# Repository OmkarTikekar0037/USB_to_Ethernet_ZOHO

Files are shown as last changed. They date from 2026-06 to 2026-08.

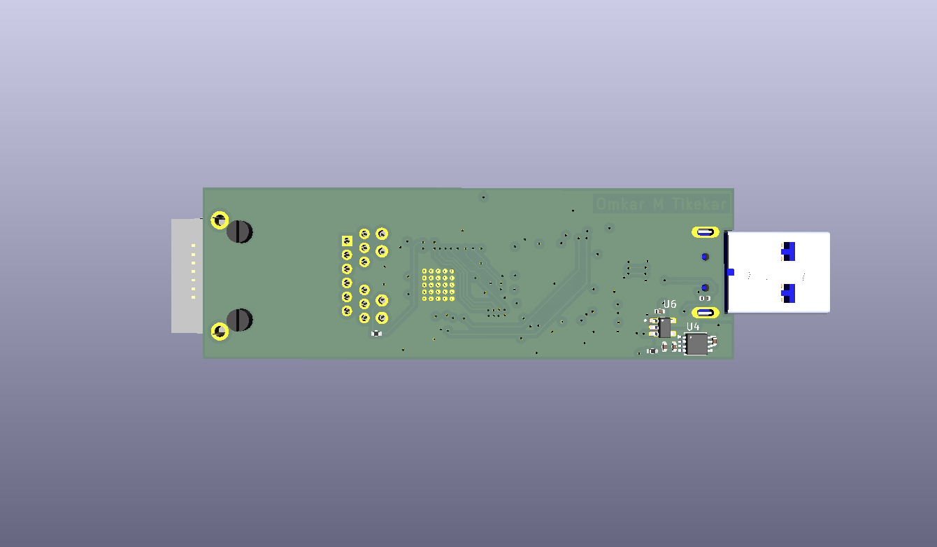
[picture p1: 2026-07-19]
images/USB_3.1_to_Ethernet_3d_B.png

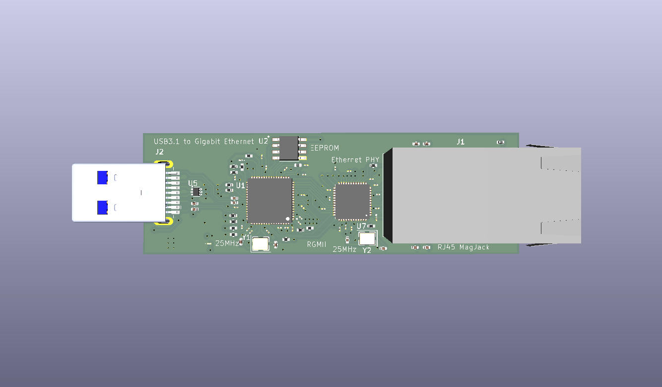
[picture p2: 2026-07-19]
images/USB_3.1_to_Ethernet_3d_F.png

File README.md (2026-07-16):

# USB 3.1 Gen 1 to Gigabit Ethernet Adapter

A custom 4-layer PCB implementing a USB 3.1 Gen 1 to Gigabit Ethernet adapter based on the **Microchip LAN7801** USB-to-Ethernet controller and the **KSZ9031RNX** Gigabit Ethernet PHY.

The project focuses on producing a manufacturable hardware design by following industry-standard practices for high-speed PCB layout, power distribution, signal integrity, and Ethernet design.

---

## Project Objectives

- Design a production-quality USB 3.1 Gen 1 to Gigabit Ethernet adapter.
- Implement a complete RGMII-based Ethernet subsystem.
- Develop a reliable multi-rail power architecture.
- Follow high-speed PCB design guidelines for USB and Gigabit Ethernet.
- Produce fabrication-ready design files with zero ERC/DRC violations.

---

## Hardware Overview

| Component | Description |
|---|---|
| LAN7801 | USB 3.1 Gen 1 to Gigabit Ethernet Controller |
| KSZ9031RNX | Gigabit Ethernet PHY |
| 93LC56 | External configuration EEPROM |
| USB Type-C | USB Interface |
| RJ45 MagJack | Ethernet Connector with Integrated Magnetics |
| TLV76733 | 3.3V LDO |
| TPS7A0212 | 1.2V LDO |

---

## System Architecture

```
USB Type-C
      │
      ▼
+--------------+
|   LAN7801    |
+--------------+
      │
     RGMII
      │
      ▼
+--------------+
| KSZ9031RNX   |
+--------------+
      │
 Ethernet MDI
      │
      ▼
 RJ45 MagJack
```

---

## Repository Structure

```text
.
├── Hardware/
│   ├── Schematic/
│   ├── PCB/
│   ├── Libraries/
│   └── Manufacturing/
│
├── Docs/
│   ├── Project_History.md
│   ├── System_Architecture.md
│   ├── Power_Architecture.md
│   ├── Ethernet_Subsystem.md
│   ├── USB_Subsystem.md
│   ├── PCB_Design.md
│   └── Debugging.md
│
├── Datasheets/
│
├── Images/
│
└── README.md
```

---

## Current Project Status

| Stage | Status |
|---|---|
| Component Selection | Completed |
| Schematic Design | Completed |
| PCB Placement | Completed |
| PCB Routing | Completed |
| ERC | Passed |
| DRC | Passed |
| Manufacturing Outputs | In Progress |
| Hardware Validation | Pending |

---

## Design Highlights

- 4-layer PCB stack-up
- Controlled impedance routing
- USB differential pair routing
- Gigabit Ethernet differential routing
- Dedicated power planes
- Multi-stage power regulation
- External EEPROM configuration
- RGMII interface between MAC and PHY
- ESD and signal protection provisions

---

## Documentation

Detailed design discussions and engineering decisions are maintained separately under the **Docs** directory.

These documents describe:

- Architecture
- Design decisions
- Power subsystem
- PCB layout methodology
- Signal integrity considerations
- Manufacturing preparation
- Debugging history

The README intentionally provides only a high-level overview.

---

## Future Work

- PCB fabrication
- Assembly
- Hardware bring-up
- USB enumeration verification
- Ethernet link validation
- Throughput testing
- Compliance verification

---

## License

Project license to be added.

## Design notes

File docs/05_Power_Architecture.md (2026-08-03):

# Power Architecture

## 1. Introduction

The power architecture provides regulated supply rails for every subsystem of the adapter, beginning with the 5 V supplied through the USB Type-A connector.

The design emphasizes:

- Stable voltage regulation
- Low-noise power distribution
- Proper subsystem isolation
- Reliable startup
- Adequate local decoupling
- Manufacturable PCB layout

The power network was designed to satisfy the requirements of both the LAN7801 controller and the KSZ9031RNX Gigabit Ethernet PHY while maintaining good signal integrity throughout the board.

---

# 2. Power Overview

The entire adapter is powered directly from the USB VBUS supply.

```

                USB VBUS (5 V)
                       │
                       ▼
             +------------------+
             |    3.3 V LDO     |
             +------------------+
                       │
        ┌──────────────┼──────────────┐
        │              │              │
        ▼              ▼              ▼
    LAN7801       KSZ9031RNX      EEPROM
      I/O             I/O
                       │
                       ▼
              +------------------+
              |    1.2 V LDO     |
              +------------------+
                       │
         ┌─────────────┴─────────────┐
         ▼                           ▼
   LAN7801 Core             KSZ9031RNX Core

```

The design uses a cascaded regulation approach where the 3.3 V rail supplies the lower-voltage regulator required for the core logic.

---

# 3. Supply Rails

## 3.1 USB VBUS (5 V)

The USB connector provides the primary power source for the board.

This rail serves as the input to the onboard voltage regulation circuitry and is not distributed directly to digital logic.

Primary responsibilities:

- System power input
- Regulator input supply

---

## 3.2 3.3 V Rail

The 3.3 V rail supplies the I/O circuitry and supporting peripherals.

Typical loads include:

- LAN7801 I/O
- KSZ9031RNX I/O
- EEPROM
- Supporting logic

This rail also serves as the input source for the 1.2 V regulator.

---

## 3.3 1.2 V Rail

The 1.2 V rail powers the internal core logic of the major integrated circuits.

Typical loads include:

- LAN7801 Core
- KSZ9031RNX Core
- Internal digital logic

Because these circuits switch at high frequency, particular attention was given to local decoupling and power plane integrity.

---

# 4. Power Tree

```

                    USB VBUS
                        │
                        ▼
                 3.3 V Regulator
                        │
      ┌─────────────────┼─────────────────┐
      │                 │                 │
      ▼                 ▼                 ▼
 LAN7801 I/O      KSZ9031 I/O        EEPROM
      │
      ▼
               1.2 V Regulator
                        │
        ┌───────────────┴───────────────┐
        ▼                               ▼
   LAN7801 Core                  KSZ9031 Core

```

Separating the I/O and core supplies reduces supply noise while allowing each voltage rail to operate within its required specification.

---

# 5. Decoupling Strategy

Power integrity depends heavily on proper local energy storage.

Each major integrated circuit includes multiple decoupling capacitors positioned close to its supply pins.

The objectives are:

- Supply transient current locally
- Reduce voltage ripple
- Minimize supply impedance
- Suppress high-frequency switching noise

Where multiple supply pins exist, each supply pin is locally decoupled according to the manufacturer recommendations.

---

# 6. Bulk Capacitance

In addition to local decoupling, bulk capacitors are placed on the primary supply rails.

These capacitors provide:

- Low-frequency energy storage
- Startup stability
- Load transient support

Bulk capacitance complements the local high-frequency decoupling network.

---

# 7. Power Distribution

Power routing was performed with the following priorities:

- Low impedance
- Short current paths
- Wide power traces where appropriate
- Continuous power planes
- Minimal voltage drop

Sensitive analog supplies were routed separately from noisy digital switching paths wherever practical.

---

# 8. Ground Strategy

A continuous ground plane forms the primary return path for all circuitry.

The ground system provides:

- Low return impedance
- Stable voltage reference
- Improved signal integrity
- Reduced electromagnetic emissions

Ground plane discontinuities beneath high-speed interfaces were avoided.

---

# 9. Startup Considerations

Reliable startup depends on all regulated rails reaching stable operating conditions before normal device operation begins.

The design considers:

- Regulator stabilization
- Power rail sequencing
- Device reset timing
- EEPROM availability during initialization

These factors ensure predictable system initialization after USB connection.

---

# 10. PCB Layout Considerations

Power distribution strongly influenced component placement.

Major layout practices include:

## Regulator Placement

Voltage regulators are positioned close to their primary loads to reduce supply path impedance.

---

## Decoupling Placement

Each decoupling capacitor is placed adjacent to its associated supply pin.

The routing between capacitor and IC supply pin is kept as short as practical.

---

## Power Plane Usage

Dedicated copper regions are used to distribute regulated supplies.

This reduces:

- IR drop
- Supply inductance
- Power distribution impedance

---

## Via Usage

Power vias are placed close to decoupling capacitors and supply pins to provide efficient current flow between PCB layers.

---

# 11. Verification

The power subsystem was verified for:

- Supply connectivity
- Regulator output routing
- Decoupling placement
- Power plane continuity
- Ground continuity
- ERC compliance
- DRC compliance

Particular attention was given to ensuring that every supply pin was connected to the correct voltage rail.

---

# 12. Design Philosophy

The power architecture follows three fundamental principles:

- Generate only the voltages required by the system.
- Deliver each voltage through a low-impedance distribution network.
- Decouple every active device as close to the load as possible.

These principles improve reliability, simplify debugging, and contribute to stable operation during high-speed communication.

---

# Related Documents

- 01_System_Architecture.md
- 02_Component_Selection.md
- 03_USB_Subsystem.md
- 04_Ethernet_Subsystem.md
- 06_EEPROM.md
- 07_PCB_Design.md

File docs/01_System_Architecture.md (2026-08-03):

# System Architecture

## 1. Introduction

This document describes the overall hardware architecture of the USB 3.1 Gen 1 to Gigabit Ethernet Adapter.

The design is partitioned into multiple functional subsystems, each responsible for a specific task in the data path, power distribution, or device configuration.

Understanding the interaction between these subsystems is essential before studying their individual implementations.

---

# 2. System Overview

The adapter converts USB 3.1 Gen 1 data received from the host computer into Gigabit Ethernet frames that can be transmitted over a standard RJ45 interface.

At the highest level, the system consists of the following major functional blocks:

- USB Interface
- USB-to-Ethernet Controller
- Gigabit Ethernet PHY
- Ethernet Magnetics
- EEPROM Configuration Memory
- Clock Generation
- Power Distribution Network
- Status Indicators

---

# 3. High-Level Block Diagram

```

                 USB HOST
                     │
                     │
             USB 3.1 Gen 1
                     │
                     ▼
        ┌──────────────────────┐
        │      USB Type-A      │
        └──────────────────────┘
                     │
                     ▼
        ┌──────────────────────┐
        │       LAN7801        │
        │ USB Ethernet MAC     │
        └──────────────────────┘
                     │
                  RGMII
                     │
                     ▼
        ┌──────────────────────┐
        │     KSZ9031RNX       │
        │ Gigabit Ethernet PHY │
        └──────────────────────┘
                     │
             Differential Pairs
                     │
                     ▼
        ┌──────────────────────┐
        │    RJ45 MagJack      │
        │  Integrated Magnetics│
        └──────────────────────┘
                     │
                Ethernet Cable

```

---

# 4. Functional Subsystems

## 4.1 USB Interface

The USB interface provides communication between the adapter and the host computer.

Its responsibilities include:

- USB SuperSpeed communication
- USB device detection
- Power input from VBUS
- Data transfer to the LAN7801 controller

The USB interface serves as the entry point for both system power and data.

---

## 4.2 Ethernet Controller

The LAN7801 acts as the central controller of the adapter.

Its primary responsibilities include:

- USB protocol handling
- Ethernet MAC implementation
- Packet buffering
- DMA operations
- Interface with external EEPROM
- Communication with the Gigabit PHY through RGMII

It forms the bridge between the USB subsystem and the Ethernet subsystem.

---

## 4.3 Ethernet PHY

The KSZ9031RNX performs physical layer processing required for Gigabit Ethernet communication.

Responsibilities include:

- RGMII interface
- 1000BASE-T physical layer
- Clock recovery
- Auto-negotiation
- Auto MDI/MDI-X
- Differential signal transmission and reception

The PHY converts digital Ethernet frames into electrical signals suitable for transmission through twisted-pair Ethernet cable.

---

## 4.4 Ethernet Magnetics

The RJ45 MagJack provides:

- Isolation transformer
- Common-mode noise rejection
- Differential signal coupling
- Cable interface

This stage electrically isolates the PCB from the external Ethernet network while preserving signal integrity.

---

## 4.5 EEPROM

An external EEPROM stores device configuration parameters required during LAN7801 initialization.

Typical information includes:

- USB descriptors
- Vendor information
- Product identification
- MAC address
- Configuration options

The controller loads these parameters during startup.

---

## 4.6 Clock Generation

Stable clock sources are required for reliable operation of both the controller and PHY.

The clock subsystem provides timing references necessary for:

- USB operation
- Ethernet operation
- PHY synchronization
- Internal PLL operation

Clock quality directly affects communication reliability.

---

## 4.7 Power Distribution

The adapter derives all operating voltages from the USB VBUS supply.

Separate regulated rails are generated for:

- Digital I/O
- Analog circuitry
- Core logic

The power architecture is discussed in detail in **Power_Architecture.md**.

---

# 5. Data Flow

The data path through the adapter is illustrated below.

```

USB Host
    │
    ▼
USB Type-A
    │
    ▼
LAN7801
    │
 RGMII Interface
    │
    ▼
KSZ9031RNX
    │
 Ethernet MDI
    │
    ▼
RJ45 MagJack
    │
    ▼
Ethernet Network

```

The reverse path follows the same sequence in the opposite direction for received Ethernet frames.

---

# 6. Power Flow

The power distribution network begins at the USB connector.

```

USB VBUS
    │
    ▼
Primary Regulation
    │
    ├────────► 3.3 V Rail
    │
    └────────► 1.2 V Rail

```

Each subsystem receives power from the appropriate regulated supply according to its operating requirements.

---

# 7. Reset Architecture

Proper initialization requires all major devices to enter a known state after power application.

The reset network ensures:

- Stable power rails before initialization
- Predictable startup sequence
- Reliable device configuration
- Proper PHY initialization

Reset sequencing is discussed in the subsystem documentation where applicable.

---

# 8. Configuration Interfaces

Several auxiliary interfaces are used internally within the design.

| Interface | Purpose |
|---|---|
| USB 3.1 | Host communication |
| RGMII | LAN7801 ↔ KSZ9031RNX |
| MDIO/MDC | PHY register configuration |
| Microwire | EEPROM communication |
| Differential Ethernet | Physical Ethernet interface |

Each interface is described in detail within its respective subsystem document.

---

# 9. Design Philosophy

The system architecture emphasizes:

- Functional partitioning
- Independent subsystem verification
- Short critical signal paths
- Reliable power delivery
- Manufacturable PCB layout
- Maintainable hardware organization

This modular organization simplified schematic development, PCB layout, and design verification throughout the project.

---

# 10. Related Documents

The following documents expand each subsystem in detail:

- USB_Subsystem.md
- Ethernet_Subsystem.md
- Power_Architecture.md
- EEPROM.md
- PCB_Design.md
- Signal_Integrity.md
- Manufacturing.md

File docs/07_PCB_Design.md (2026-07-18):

# PCB Design

## 1. Introduction

This document summarizes the PCB design methodology adopted for the USB 3.1 Gen 1 to Gigabit Ethernet Adapter.

The focus is on the design decisions that directly influenced signal integrity, power integrity, manufacturability, and overall board reliability.

---

# 2. PCB Stack-Up

A four-layer PCB stack-up was selected to satisfy the routing and signal integrity requirements of both USB SuperSpeed and Gigabit Ethernet interfaces.

The adopted stack-up is:

```
Layer 1 : High-Speed Signals
Layer 2 : Continuous Ground Plane
Layer 3 : Power Plane
Layer 4 : Signals
```

### Why a Four-Layer PCB?

The design contains several high-speed interfaces that require continuous reference planes and controlled impedance routing.

Compared to a two-layer PCB, the selected stack-up provides:

- Improved signal integrity
- Lower EMI
- Better return current paths
- Easier impedance control
- Improved power distribution
- Simplified routing

---

# 3. Component Placement

Component placement was completed before routing.

The placement strategy prioritized:

- Short USB routing
- Short RGMII interface
- Short MDI differential pairs
- Proper crystal placement
- Efficient power distribution

Critical devices were placed according to signal flow rather than mechanical convenience.

---

# 4. USB SuperSpeed Routing

The USB SuperSpeed differential pairs were routed directly between the USB Type-A connector and the LAN7801.

Routing objectives included:

- 90 Ω differential impedance
- Continuous ground reference
- Minimal via usage
- Length matching within each pair
- Smooth routing geometry
- Minimal discontinuities

---

# 5. RGMII Routing

The RGMII interface between the LAN7801 and KSZ9031RNX was treated as one of the most timing-sensitive sections of the design.

Layout considerations included:

- Short trace lengths
- Length matching
- Reduced skew
- Continuous reference plane
- Minimal routing detours

---

# 6. Ethernet MDI Routing

The four Ethernet differential pairs were routed from the PHY to the integrated MagJack.

Routing followed Gigabit Ethernet layout recommendations.

Design goals included:

- 100 Ω differential impedance
- Constant pair spacing
- Length matching within each pair
- Smooth routing
- Reduced discontinuities
- Minimal layer transitions

---

# 7. Clock Layout

The 25 MHz reference crystal was placed immediately adjacent to the PHY.

Routing between the PHY and crystal was kept:

- Short
- Symmetrical
- Free from nearby high-speed signals

This minimizes clock noise and improves oscillator stability.

---

# 8. Power Distribution

Power routing emphasized low impedance and clean supply delivery.

The implementation includes:

- Wide power traces where required
- Dedicated power plane
- Local decoupling for every active device
- Bulk capacitance near regulators

---

# 9. Grounding Strategy

A continuous ground plane was maintained beneath all high-speed interfaces.

The ground plane provides:

- Controlled return current paths
- Reduced EMI
- Stable reference for impedance-controlled routing

Plane interruptions beneath critical signals were avoided.

---

# 10. Design Verification

Before manufacturing, the PCB underwent multiple verification stages.

Verification included:

- ERC
- DRC
- Differential pair inspection
- Power connectivity review
- Footprint verification
- Connector orientation review

The objective was to eliminate layout-related issues before fabrication.

---

# 11. Summary

The PCB layout was driven primarily by signal integrity and manufacturability rather than routing convenience.

Particular attention was given to:

- USB SuperSpeed routing
- RGMII timing
- Gigabit Ethernet differential routing
- Power integrity
- Ground reference continuity

The final design is intended to provide a robust hardware platform suitable for fabrication and hardware validation.

---

# Related Documents

- 03_USB_Subsystem.md
- 04_Ethernet_Subsystem.md
- 05_Power_Architecture.md

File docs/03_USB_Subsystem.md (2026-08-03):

# USB Subsystem

## 1. Introduction

The USB subsystem provides the primary communication interface between the host computer and the adapter.

In addition to transferring Ethernet frames, the USB interface also supplies power to the entire system through the USB Type-A connector.

This document describes the implementation of the USB subsystem, including the connector, protection circuitry, power entry, and interface to the LAN7801 controller.

---

# 2. Objectives

The USB subsystem was designed to achieve the following objectives:

- Reliable USB 3.1 Gen 1 communication
- Stable power delivery from USB VBUS
- Compliance with USB Type-A device connection requirements
- Protection against ESD events
- Controlled impedance routing for SuperSpeed differential pairs
- Seamless integration with the LAN7801 controller

---

# 3. USB Architecture

```
                 USB Host
                     │
                     │
                     │
                     ▼
          ┌─────────────────────┐
          │ USB Type-A Connector│
          └─────────────────────┘
                     │
      ┌──────────────┼──────────────┐
      │              │              │
      ▼              ▼              ▼
    VBUS         USB Data      Configuration
                    │             Channel
                    │
                    ▼
          ┌─────────────────────┐
          │      LAN7801        │
          └─────────────────────┘
```

---

# 4. USB Type-A Connector

The USB Type-A connector serves as the interface between the host computer and the adapter.

Its functions include:

- Receiving USB SuperSpeed signals
- Receiving USB 2.0 signals
- Supplying system power through VBUS

The connector is implemented as a USB device interface.

---

# 5. USB Data Path

The SuperSpeed differential pairs are routed directly between the USB Type-A connector and the LAN7801.

Primary routing objectives included:

- Controlled differential impedance
- Continuous reference plane
- Minimal via count
- Length matching within each differential pair
- Smooth routing without unnecessary discontinuities
- Isolation from noisy switching circuits

Signal integrity was prioritized during placement and routing.

---

# 6. USB 2.0 Interface

The USB 2.0 differential pair is routed alongside the SuperSpeed interface.

Although Gigabit Ethernet communication utilizes the SuperSpeed interface, USB 2.0 remains necessary for:

- Device enumeration
- Backward compatibility
- Standard USB operation

The routing follows standard differential pair design practices.

---

# 7. Power Entry

System power is obtained directly from the USB VBUS supply.

VBUS serves as the primary input to the onboard power distribution network.

Subsequent voltage regulation generates the required operating voltages for the remaining subsystems.

The power architecture is discussed separately in **Power_Architecture.md**.

---

# 8. Protection Circuitry

To improve robustness, the USB interface includes protection against external electrical disturbances.

Protection features include:

- ESD protection for high-speed data lines
- ESD protection for Configuration Channel pins
- Protection of VBUS input
- Proper grounding strategy for transient current dissipation

Component placement minimizes the distance between the connector and protection devices.

---

# 9. PCB Layout Considerations

The USB interface imposes strict layout requirements.

Key design considerations include:

## Component Placement

- LAN7801 positioned close to the USB connector
- Short SuperSpeed routing paths
- Minimal signal discontinuities

## Differential Pair Routing

- Controlled impedance
- Constant spacing
- Length matching
- No unnecessary stubs
- Reduced via usage

## Reference Plane

The SuperSpeed pairs are routed above a continuous ground reference plane to maintain impedance and provide a low-inductance return path.

## Return Current

High-speed return currents are allowed to flow directly beneath their associated signal traces by avoiding interruptions in the reference plane.

---

# 10. Verification

The USB subsystem was reviewed for:

- Connector pin assignments
- Differential pair continuity
- Differential pair polarity
- Power connectivity
- ESD device placement
- CC resistor implementation
- ERC compliance
- PCB DRC compliance

---

# 11. Summary

The USB subsystem provides both communication and power entry for the adapter.

Its implementation emphasizes:

- Reliable high-speed communication
- Controlled impedance routing
- Proper Type-C device configuration
- Robust protection against external disturbances
- Clean integration with the LAN7801 controller

Together with the Ethernet subsystem, it forms the primary communication path of the adapter.

---

# Related Documents

- 01_System_Architecture.md
- 02_Component_Selection.md
- 04_Ethernet_Subsystem.md
- 05_Power_Architecture.md
- 07_PCB_Design.md

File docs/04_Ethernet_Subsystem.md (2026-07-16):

# Ethernet Subsystem

## 1. Introduction

The Ethernet subsystem implements the complete physical communication path between the LAN7801 USB-to-Ethernet controller and the external Gigabit Ethernet network.

The subsystem consists of the Ethernet MAC integrated within the LAN7801, the KSZ9031RNX Gigabit Ethernet PHY, the RGMII interface connecting both devices, the Ethernet magnetics, and the RJ45 connector.

Together, these components enable IEEE 802.3 compliant 10 Mbps, 100 Mbps and 1000 Mbps Ethernet communication.

---

# 2. Objectives

The Ethernet subsystem was designed with the following objectives:

- Reliable Gigabit Ethernet communication
- Short and well-controlled RGMII routing
- Stable PHY operation
- Proper clock distribution
- Robust power distribution
- Manufacturable PCB layout
- Compliance with recommended PHY layout practices

---

# 3. Ethernet Architecture

```

                LAN7801
           (Ethernet MAC)
                   │
                   │ RGMII
                   │
                   ▼
            KSZ9031RNX
          Gigabit Ethernet PHY
                   │
         MDI Differential Pairs
                   │
                   ▼
          RJ45 MagJack
      (Integrated Magnetics)
                   │
             Ethernet Cable

```

---

# 4. Ethernet MAC

The Ethernet Media Access Controller (MAC) is integrated within the LAN7801.

Its responsibilities include:

- Ethernet frame generation
- Frame reception
- CRC generation and verification
- Packet buffering
- DMA transfers
- Communication with the USB subsystem

The MAC communicates with the external PHY using the RGMII interface.

---

# 5. Gigabit Ethernet PHY

The KSZ9031RNX performs all Physical Layer (PHY) operations required for Ethernet communication.

Major responsibilities include:

- RGMII interface
- 10BASE-T operation
- 100BASE-TX operation
- 1000BASE-T operation
- Auto-negotiation
- Auto MDI/MDI-X
- Clock recovery
- Line encoding and decoding
- Cable interface

The PHY converts digital Ethernet frames into differential electrical signals suitable for transmission through twisted-pair Ethernet cable.

---

# 6. RGMII Interface

Communication between the LAN7801 and KSZ9031RNX occurs through the Reduced Gigabit Media Independent Interface (RGMII).

Signals include:

- GTX_CLK
- TX_CTL
- TXD[3:0]
- RX_CLK
- RX_CTL
- RXD[3:0]

The interface also includes:

- MDC
- MDIO

for PHY management and configuration.

---

# 7. MDIO Management Interface

The MDIO interface provides software access to the PHY registers.

Typical functions include:

- PHY identification
- Link status monitoring
- Auto-negotiation control
- Speed selection
- Duplex configuration
- Diagnostic information

This interface is intended for configuration and monitoring rather than high-speed data transfer.

---

# 8. Ethernet Magnetics

The RJ45 MagJack integrates the required isolation transformer and common-mode filtering components.

Its primary functions are:

- Galvanic isolation
- Common-mode noise rejection
- Impedance matching
- Differential signal coupling
- External Ethernet connection

The integrated solution simplifies PCB layout while reducing component count.

---

# 9. Clocking

Reliable Ethernet communication depends on accurate clock generation.

The subsystem utilizes a dedicated 25 MHz reference crystal connected to the PHY.

The PHY internally generates the clocks required for Ethernet operation and provides the necessary timing for communication with the MAC.

Proper crystal placement and routing were treated as critical PCB design constraints.

---

# 10. Power Distribution

The Ethernet subsystem utilizes multiple regulated supply rails.

These include:

- PHY Core Supply
- PHY Analog Supply
- PHY I/O Supply

Each supply rail is independently decoupled according to the manufacturer recommendations.

Special attention was given to minimizing noise coupling between analog and digital sections.

---

# 11. PCB Layout Considerations

Because the Ethernet subsystem contains multiple high-speed interfaces, PCB layout significantly influences system performance.

Major design considerations included:

## Component Placement

- PHY placed close to LAN7801
- Short RGMII routing
- Crystal located adjacent to PHY
- Magnetics positioned close to RJ45 connector

---

## RGMII Routing

The RGMII interface was routed with emphasis on:

- Short trace lengths
- Length matching
- Continuous reference planes
- Minimal vias
- Reduced skew

Signal timing requirements were considered throughout routing.

---

## Ethernet Differential Pairs

The four MDI differential pairs between the PHY and MagJack were routed using controlled impedance practices.

Routing objectives included:

- Constant pair spacing
- Length matching within each pair
- Minimal discontinuities
- Smooth routing geometry
- Continuous reference plane

---

## Return Current

Continuous ground reference planes were maintained beneath all high-speed Ethernet signals to provide low-inductance return paths.

Plane splits beneath critical routing were avoided.

---

## Crystal Placement

The reference crystal was positioned immediately adjacent to the PHY.

Routing between the PHY and crystal was kept short and symmetrical to minimize clock noise and improve oscillator stability.

---

# 12. Verification

The Ethernet subsystem underwent verification for:

- RGMII connectivity
- Differential pair polarity
- PHY power rails
- Crystal connections
- MDIO interface
- Strap pin configuration
- Decoupling placement
- Ethernet pair continuity
- ERC compliance
- DRC compliance

---

# 13. Summary

The Ethernet subsystem forms the communication bridge between the LAN7801 controller and the external Ethernet network.

The implementation emphasizes:

- Reliable Gigabit Ethernet communication
- Stable PHY operation
- Proper clock generation
- Controlled impedance routing
- Clean subsystem partitioning
- Manufacturable PCB layout

---

# Related Documents

- 01_System_Architecture.md
- 02_Component_Selection.md
- 03_USB_Subsystem.md
- 05_Power_Architecture.md
- 07_PCB_Design.md

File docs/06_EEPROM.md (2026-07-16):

# EEPROM Subsystem

## 1. Introduction

The adapter utilizes an external serial EEPROM to store non-volatile configuration data required by the LAN7801 during system initialization.

Separating configuration data from the controller provides flexibility during manufacturing and allows device-specific parameters to be updated without modifying the hardware.

The EEPROM is accessed automatically by the LAN7801 during the power-up sequence.

---

# 2. Objectives

The EEPROM subsystem was designed to:

- Store permanent device configuration
- Provide USB identification information
- Store Ethernet-related configuration
- Support production programming
- Enable board-specific customization

---

# 3. Architecture

```

                 LAN7801
                     │
         Microwire Serial Interface
                     │
                     ▼
              +--------------+
              |   93LC56     |
              |   EEPROM     |
              +--------------+

```

The EEPROM acts as a non-volatile configuration memory and is not involved in normal Ethernet data transfer.

---

# 4. Stored Information

The EEPROM stores configuration information used during device initialization.

Typical contents include:

- Vendor ID (VID)
- Product ID (PID)
- USB device descriptors
- Manufacturer information
- Product string
- MAC address
- LAN7801 configuration options

The exact EEPROM image is generated according to the project requirements and programmed during manufacturing.

---

# 5. Initialization Sequence

During startup, the LAN7801 checks for the presence of a valid external EEPROM.

If a valid configuration is detected, the controller loads the stored parameters into its internal configuration registers before beginning normal USB operation.

This process is transparent to the host computer.

---

# 6. Interface

Communication between the LAN7801 and the EEPROM occurs through the Microwire serial interface.

The interface provides:

- Read operations during startup
- Configuration data transfer
- Reliable non-volatile storage

Since EEPROM access occurs primarily during initialization, the interface has minimal impact on normal Ethernet operation.

---

# 7. Power Supply

The EEPROM operates from the regulated 3.3 V supply rail.

Local decoupling is provided adjacent to the device to ensure reliable operation during power-up and configuration loading.

---

# 8. PCB Layout Considerations

Although the EEPROM is not a high-speed device, proper placement improves system reliability.

Design considerations include:

## Placement

- Located close to the LAN7801
- Short serial interface traces
- Convenient routing to the controller

---

## Power

- Local decoupling capacitor positioned adjacent to the supply pin
- Short connection to the 3.3 V rail
- Direct connection to the ground plane

---

## Signal Routing

The Microwire interface traces were kept short and free from unnecessary routing complexity.

Because the interface operates at relatively low speed, impedance-controlled routing was not required.

---

# 9. Manufacturing Considerations

The EEPROM is programmed with the required configuration image during board production.

Programming may include:

- USB identification data
- Device configuration
- Factory MAC address
- Customer-specific parameters (if applicable)

This allows identical hardware assemblies to be configured for different production variants without modifying the PCB.

---

# 10. Verification

The EEPROM subsystem was verified for:

- Correct device selection
- Supply connectivity
- Microwire interface continuity
- Decoupling placement
- ERC compliance
- DRC compliance

Additional verification is performed during hardware bring-up by confirming successful configuration loading by the LAN7801.

---

# 11. Summary

Although physically small, the EEPROM plays an essential role during system initialization.

It enables permanent storage of device-specific configuration while keeping the hardware design flexible and suitable for manufacturing.

Because configuration data resides externally, updates can be made without redesigning the PCB or replacing the controller.

---

# Related Documents

- 01_System_Architecture.md
- 02_Component_Selection.md
- 03_USB_Subsystem.md
- 04_Ethernet_Subsystem.md
- 05_Power_Architecture.md
- 07_PCB_Design.md

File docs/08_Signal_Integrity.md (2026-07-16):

# Signal Integrity

## 1. Introduction

The USB 3.1 Gen 1 to Gigabit Ethernet Adapter contains multiple high-speed digital interfaces whose performance depends heavily on PCB layout.

This document summarizes the signal integrity considerations adopted during the design process to ensure reliable operation of the USB SuperSpeed, RGMII, and Gigabit Ethernet interfaces.

The focus is on practical implementation decisions rather than theoretical analysis.

---

# 2. High-Speed Interfaces

The following interfaces were treated as signal integrity critical.

| Interface | Requirement |
|---|---|
| USB 3.1 SuperSpeed | Controlled impedance differential routing |
| RGMII | Timing-controlled parallel interface |
| Ethernet MDI | Controlled impedance differential routing |
| 25 MHz Crystal | Low-noise clock routing |

Each interface imposes different routing constraints and therefore required separate design considerations.

---

# 3. Controlled Impedance Routing

Controlled impedance routing was implemented wherever required by the interface specification.

Target impedances:

| Interface | Target |
|---|---|
| USB SuperSpeed | 90 Ω Differential |
| Ethernet MDI | 100 Ω Differential |

The PCB stack-up and routing geometry were selected accordingly.

---

# 4. Differential Pair Routing

Differential pairs were routed together throughout the design.

The routing objectives included:

- Constant spacing
- Parallel routing
- Equal electrical length within each pair
- Minimal discontinuities
- Smooth corner transitions
- Reduced via usage

Maintaining pair symmetry minimizes differential skew and preserves signal quality.

---

# 5. Return Current Paths

High-speed signals always require a low-impedance return path.

To support this:

- Continuous ground planes were maintained beneath critical routing.
- Plane discontinuities beneath high-speed traces were avoided.
- Reference plane transitions were minimized.

These practices reduce return path inductance and improve signal integrity.

---

# 6. USB SuperSpeed

The USB SuperSpeed interface received particular attention due to its operating frequency.

Routing considerations included:

- Short differential routing
- Controlled impedance
- Minimal stubs
- Minimal vias
- Continuous reference plane
- Isolation from switching regulators and clock circuitry

---

# 7. RGMII Interface

Although RGMII operates at lower frequencies than USB SuperSpeed, it is significantly more sensitive to timing mismatch.

Routing emphasized:

- Short trace lengths
- Length matching
- Reduced skew
- Consistent reference plane
- Clean routing between MAC and PHY

Maintaining timing relationships across the bus was prioritized over routing convenience.

---

# 8. Ethernet Differential Routing

The four MDI differential pairs between the PHY and MagJack were routed according to Gigabit Ethernet layout recommendations.

Routing objectives included:

- 100 Ω differential impedance
- Constant pair spacing
- Minimal pair skew
- Smooth routing
- Short path to the MagJack

---

# 9. Clock Signal Integrity

The 25 MHz reference crystal is one of the most sensitive portions of the design.

To minimize clock degradation:

- The crystal was placed adjacent to the PHY.
- Clock traces were kept short.
- Routing was kept symmetrical.
- High-speed routing was kept away from the oscillator circuitry.

These measures improve oscillator stability and reduce susceptibility to external noise.

---

# 10. Power Integrity

Signal integrity is closely related to power quality.

To reduce supply-induced noise:

- Local decoupling capacitors were placed adjacent to every active device.
- Bulk capacitance was provided near the regulators.
- Low-impedance power distribution was maintained throughout the PCB.

A stable power network reduces supply ripple and improves high-speed communication reliability.

---

# 11. Crosstalk Reduction

PCB routing was organized to minimize electromagnetic coupling between unrelated signals.

This included:

- Maintaining spacing between high-speed interfaces.
- Avoiding long parallel runs where unnecessary.
- Separating clock routing from switching power circuitry.
- Keeping sensitive analog sections away from noisy digital signals.

---

# 12. Layer Stack-Up

Signal integrity was a major factor in selecting the four-layer PCB stack-up.

```
Layer 1 : High-Speed Signals

Layer 2 : Continuous Ground Plane

Layer 3 : Power Plane

Layer 4 : Remaining Signals
```

This arrangement provides:

- Stable reference planes
- Controlled impedance
- Improved return current paths
- Reduced electromagnetic emissions

---

# 13. Verification

The PCB layout was reviewed to verify:

- Differential pair continuity
- Differential impedance constraints
- Pair polarity
- Length matching
- Ground plane continuity
- Crystal routing
- High-speed component placement

These reviews were completed prior to manufacturing.

---

# 14. Summary

Signal integrity considerations influenced nearly every stage of the PCB design.

Particular attention was given to:

- Controlled impedance routing
- Differential pair routing
- Return current paths
- RGMII timing
- Clock placement
- Power integrity
- Crosstalk reduction

These practices contribute to reliable operation of the USB and Gigabit Ethernet interfaces while improving overall robustness of the design.

---

# Related Documents

- 03_USB_Subsystem.md
- 04_Ethernet_Subsystem.md
- 05_Power_Architecture.md
- 07_PCB_Design.md

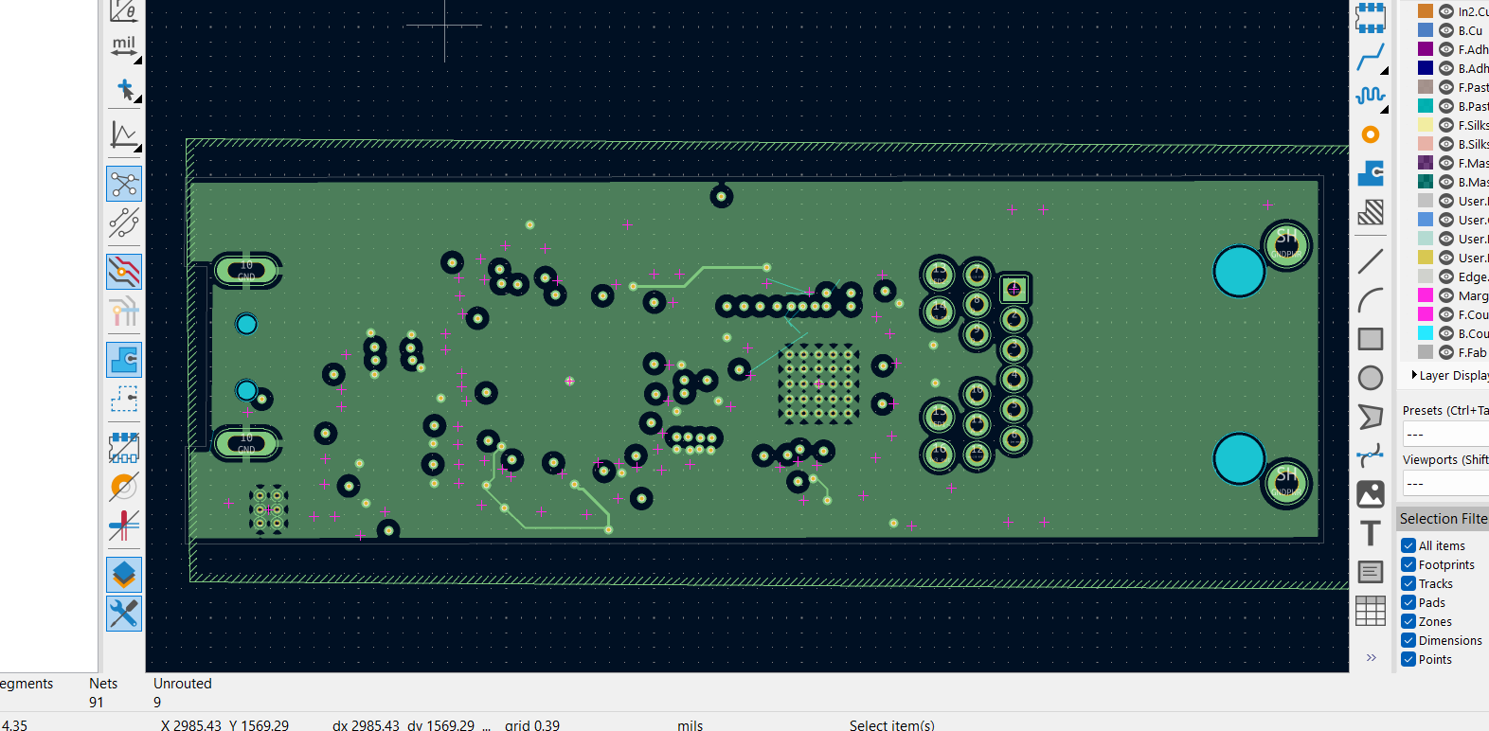
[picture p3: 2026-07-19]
images/USB_3.1_to_Ethernet_Gnd.png

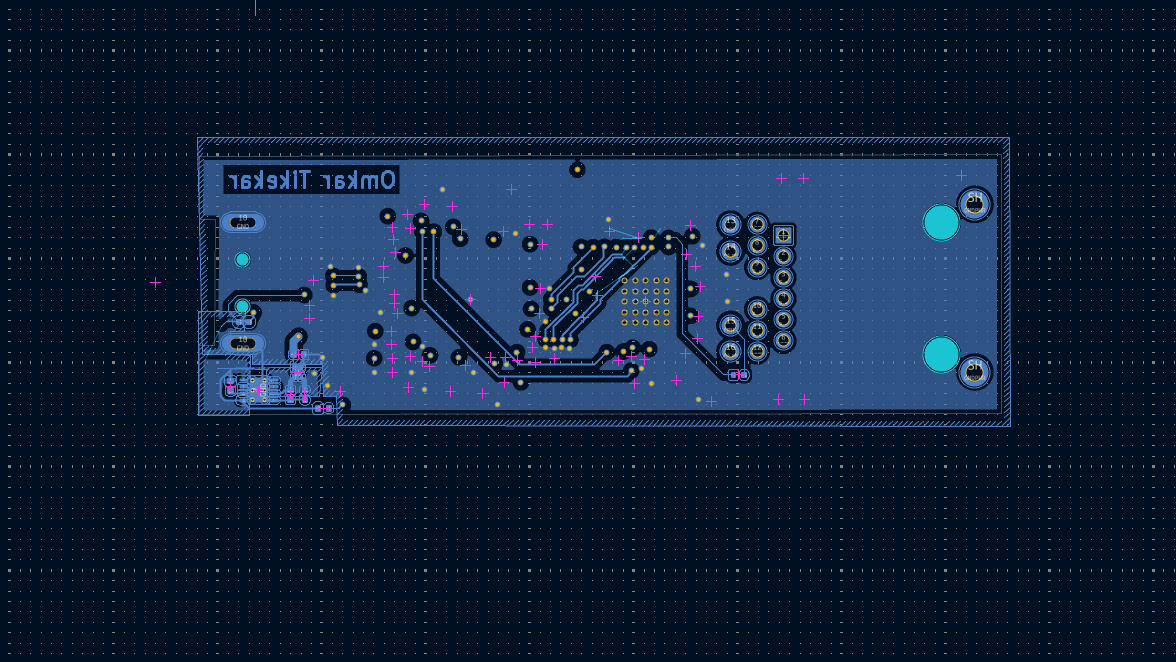
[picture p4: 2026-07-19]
images/USB_3.1_to_Ethernet_B.png

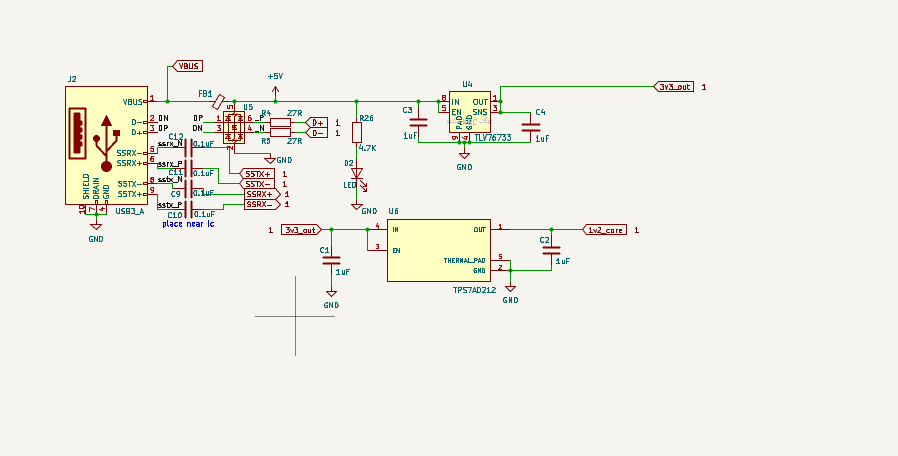
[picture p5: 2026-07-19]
images/USB_3.1_to_Ethernet_3d_Sch2.png

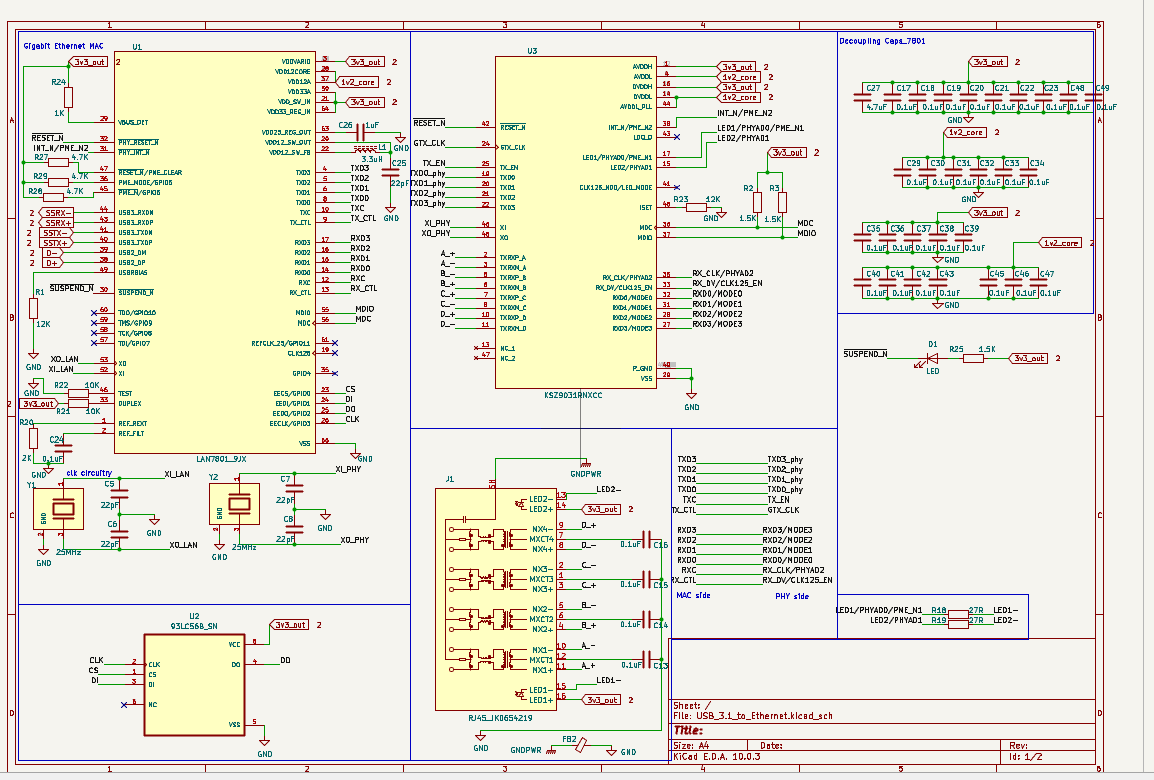
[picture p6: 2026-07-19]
images/USB_3.1_to_Ethernet_3d_Sch1.png

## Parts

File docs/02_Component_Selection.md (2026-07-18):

# Component Selection

## 1. Introduction

This document summarizes the major components used in the USB 3.1 Gen 1 to Gigabit Ethernet Adapter and their roles within the overall system architecture.

The objective is to document the purpose of each component and the considerations that influenced its selection. Since several devices were specified as part of the project requirements, this document focuses primarily on system integration rather than evaluating alternative solutions.

---

# 2. Primary Components

| Component | Function |
|---|---|
| LAN7801 | USB-to-Gigabit Ethernet Controller |
| KSZ9031RNX | Gigabit Ethernet PHY |
| 93LC56 | External Configuration EEPROM |
| USB Type-A Plug | USB Interface |
| RJ45 MagJack | Ethernet Connector with Integrated Magnetics |
| TLV76733 | 3.3 V Voltage Regulator |
| TPS7A0212 | 1.2 V Voltage Regulator |
| 25 MHz Crystal | System Clock Source |

---

# 3. LAN7801

## Role

The LAN7801 serves as the primary controller of the adapter.

It performs:

- USB device communication
- Ethernet MAC functions
- Packet buffering
- DMA operations
- External EEPROM access
- RGMII communication with the PHY

As this device was specified by the project requirements, the hardware architecture was developed around its interface and design recommendations.

---

# 4. KSZ9031RNX Gigabit PHY

## Role

The KSZ9031RNX provides the physical layer required for Gigabit Ethernet communication.

It interfaces directly with the LAN7801 through the RGMII bus and converts digital Ethernet frames into differential electrical signals suitable for transmission over twisted-pair Ethernet cable.

### Selection Considerations

The device integrates several features that simplify PCB implementation, including:

- Native RGMII interface
- Integrated termination resistors
- Auto-negotiation
- Auto MDI/MDI-X
- Clock skew adjustment
- Extensive configuration through MDIO

These capabilities reduce external component count while providing flexibility during hardware bring-up.

---

# 5. 93LC56 EEPROM

## Role

The EEPROM stores non-volatile configuration data required during controller initialization.

Typical stored information includes:

- USB descriptors
- Vendor ID
- Product ID
- Device configuration
- MAC address

Separating configuration from the controller allows firmware-independent customization of the hardware.

---

# 6. USB Type-A Connector

## Role

The USB Type-A connector provides:

- USB SuperSpeed interface
- USB 2.0 compatibility
- System power input
- Mechanical connection to the host

---

# 7. RJ45 MagJack

## Role

The RJ45 connector integrates both the Ethernet connector and the required isolation magnetics.

Its responsibilities include:

- Galvanic isolation
- Common-mode noise suppression
- Differential signal coupling
- External cable connection

Using an integrated MagJack reduces routing complexity and minimizes external magnetic components.

---

# 8. Voltage Regulators

## 8.1 TLV76733

Provides the regulated 3.3 V supply used by:

- LAN7801 I/O
- KSZ9031RNX I/O
- EEPROM
- Supporting circuitry

### Selection Considerations

- Low output noise
- Stable regulation
- Suitable output current
- Compact footprint
- Good transient response

---

## 8.2 TPS7A0212

Provides the regulated 1.2 V rail required for internal core supplies.

### Selection Considerations

- Low-noise output
- Excellent line regulation
- Small PCB footprint
- Stable operation with ceramic capacitors

---

# 9. 25 MHz Crystal

A precision 25 MHz crystal provides the reference clock required for Ethernet operation.

Clock stability directly influences:

- PHY synchronization
- PLL operation
- Ethernet timing
- Reliable link establishment

Special attention was given to crystal placement and routing during PCB layout.

---

# 10. Passive Components

Although passive components are individually simple, they play a critical role in overall system reliability.

The design includes:

- Power supply decoupling capacitors
- Bulk capacitors
- Pull-up resistors
- Pull-down resistors
- Bias resistors
- Filtering components
- Termination resistors where required

Passive component values were selected according to the recommendations provided in the respective device datasheets.

---

# 11. Design Considerations

Component selection throughout the project emphasized:

- Compatibility between subsystems
- Availability of documentation
- PCB layout simplicity
- Manufacturability
- Electrical reliability
- Long-term maintainability

Wherever possible, the design follows the reference recommendations published by the component manufacturers while maintaining a layout optimized for this specific application.

---

# 12. Related Documents

Additional information regarding the implementation of these components can be found in:

- 03_USB_Subsystem.md
- 04_Ethernet_Subsystem.md
- 05_Power_Architecture.md
- 06_EEPROM.md
- 07_PCB_Design.md

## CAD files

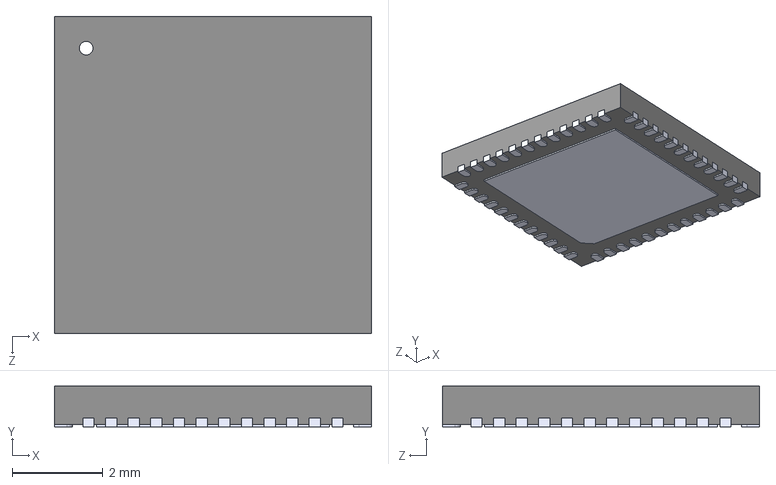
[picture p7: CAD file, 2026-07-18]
3-D models/KSZ9031RNXIC.STEP
7.00 x 0.9 x 7.00 mm

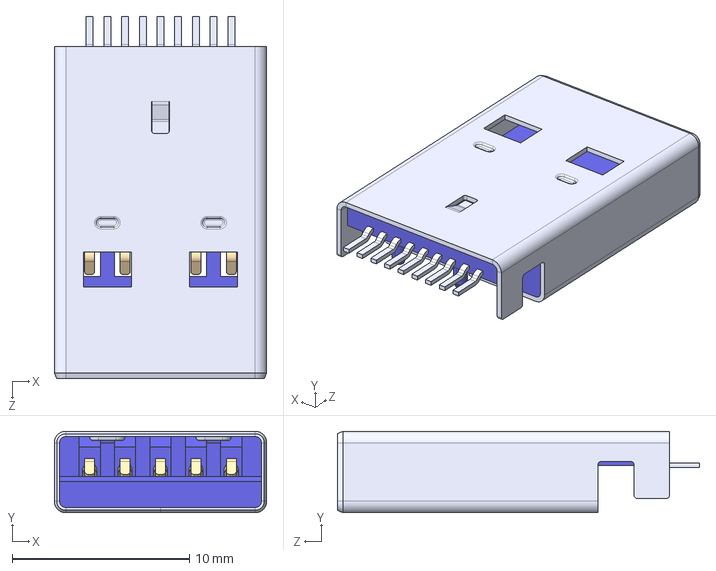
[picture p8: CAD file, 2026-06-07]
A-USB3_A-LP-SMT1.step
12.0 x 4.60 x 20.4 mm

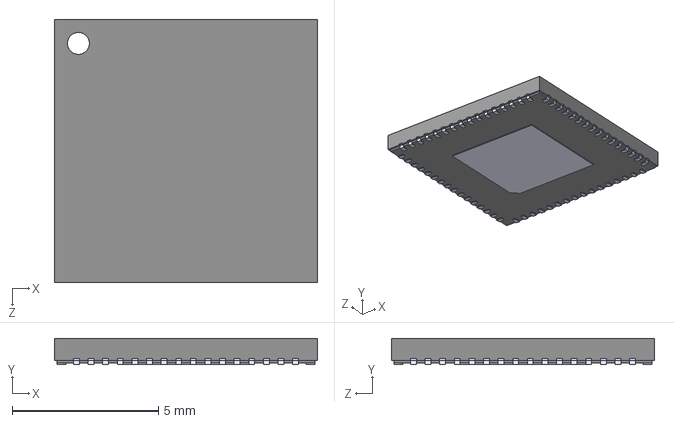
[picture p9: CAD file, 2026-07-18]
3-D models/LAN7801_9JX.STEP
9.00 x 0.9 x 9.00 mm

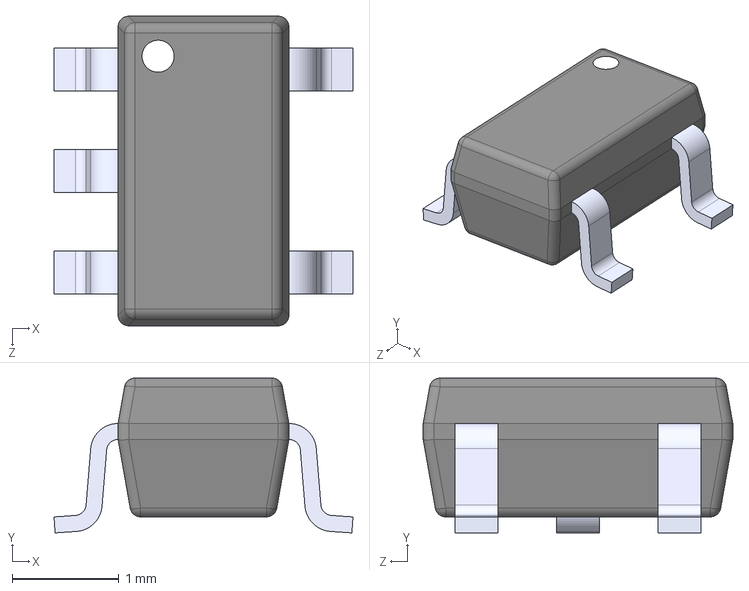
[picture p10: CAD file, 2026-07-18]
3-D models/TPS7A0212PDBVR.step
2.80 x 1.45 x 2.90 mm

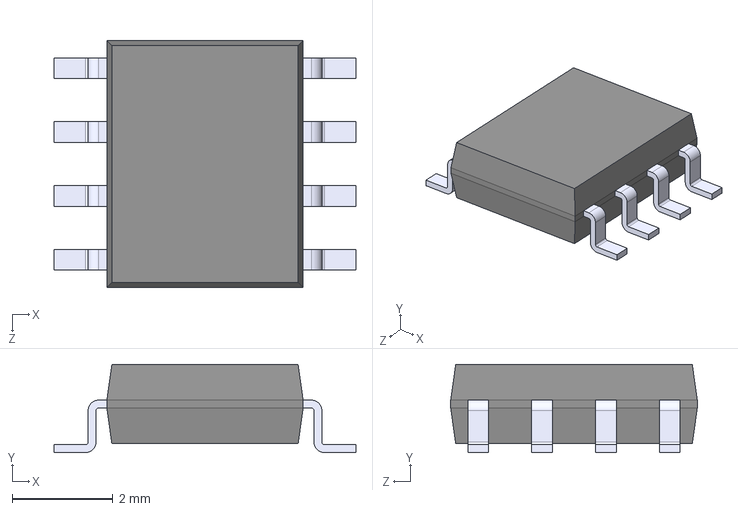
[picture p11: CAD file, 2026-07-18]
3-D models/93LC56-I_SN.STEP
6.00 x 1.75 x 4.90 mm

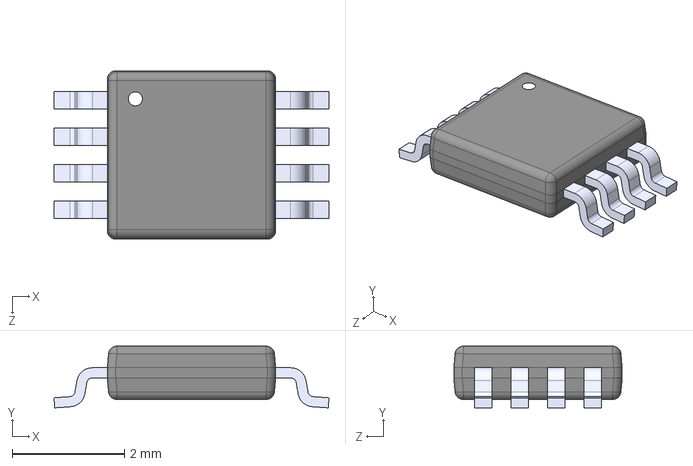
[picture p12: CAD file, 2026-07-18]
3-D models/TLV76733DGNR--3DModel-STEP-56544.STEP
4.90 x 1.10 x 3.00 mm

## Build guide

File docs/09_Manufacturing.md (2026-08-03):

# Manufacturing

## 1. Introduction

This document summarizes the manufacturing deliverables and design checks performed prior to PCB fabrication and assembly.

The objective is to ensure that the completed PCB design can be transferred to a PCB manufacturer and assembler without introducing avoidable production errors.

---

# 2. Manufacturing Outputs

The following manufacturing files are generated from the PCB design.

| Output | Purpose |
|---|---|
| Gerber Files | PCB fabrication |
| Drill Files | Hole and via locations |
| Bill of Materials (BOM) | Component procurement |
| Pick and Place (Position) File | Automated component assembly |
| Assembly Drawings | Manual and automated assembly reference |

These files collectively describe the physical implementation of the design.

---

# 3. Design Rule Verification

Before releasing the design for manufacturing, the PCB was verified using KiCad's Design Rule Check (DRC).

The review included:

- Minimum trace width
- Minimum spacing
- Via dimensions
- Pad clearances
- Copper-to-edge clearance
- Silkscreen overlap
- Unconnected nets

The objective was to eliminate layout violations prior to fabrication.

---

# 4. Electrical Verification

Electrical Rule Check (ERC) was performed on the schematic before PCB release.

Verification included:

- Power pin connections
- Driver conflicts
- Floating inputs
- Missing connections
- Net consistency
- Component annotation

This ensured consistency between the schematic and PCB implementation.

---

# 5. Footprint Verification

Each component footprint was reviewed against the manufacturer's mechanical drawings.

Verification included:

- Package dimensions
- Pin numbering
- Orientation
- Pad geometry
- Courtyard clearance

Particular attention was given to fine-pitch integrated circuits and the USB Type-A connector.

---

# 6. Assembly Considerations

The PCB layout was developed with automated assembly in mind.

Considerations included:

- Consistent component orientation where practical
- Adequate spacing between components
- Clear reference designators
- Accessible fiducial locations
- Proper polarity markings for polarized components

These practices simplify inspection and reduce assembly errors.

---

# 7. PCB Fabrication Requirements

The PCB was designed for fabrication using the following characteristics:

| Parameter | Value |
|---|---|
| PCB Layers | 4 |
| Surface Finish | ENIG *(or manufacturer selected)* |
| Copper Weight | 1 oz *(unless otherwise specified)* |
| PCB Material | FR-4 |
| PCB Thickness | 1.6 mm *(design target)* |
| Controlled Impedance | Required |

Final fabrication parameters should be confirmed with the selected PCB manufacturer.

---

# 8. Assembly Inspection

Prior to electrical testing, the assembled PCB should be visually inspected for:

- Component orientation
- Missing components
- Solder bridges
- Tombstoned passive components
- Fine-pitch solder quality
- Connector alignment
- Mechanical damage

Any visible defects should be corrected before applying power.

---

# 9. Pre-Power Checks

Before connecting the board to a USB host, the following inspections are recommended:

- Verify power-to-ground resistance
- Check for shorts between supply rails
- Confirm regulator output continuity
- Inspect USB differential pair routing
- Inspect Ethernet differential pair routing
- Verify crystal installation
- Verify EEPROM orientation

These checks reduce the likelihood of damage during first power-up.

---

# 10. Manufacturing Checklist

The following checklist should be completed before releasing the design.

| Item | Status |
|---|---|
| ERC Passed | ✓ |
| DRC Passed | ✓ |
| Component Annotation Complete | ✓ |
| Footprints Verified | ✓ |
| BOM Generated | ✓ |
| Pick and Place File Generated | ✓ |
| Gerbers Generated | ✓ |
| Drill Files Generated | ✓ |
| Final Design Review Completed | ✓ |

---

# 11. Revision Control

All manufacturing files should correspond to a single tagged hardware revision.

For each hardware revision, archive:

- Schematic
- PCB layout
- Gerber package
- Drill files
- BOM
- Pick and Place file
- Manufacturing notes

This ensures complete traceability of released hardware.

---

# 12. Summary

The manufacturing package represents the transition from design to physical hardware.

Completing the verification and documentation steps described above reduces fabrication risk, simplifies assembly, and improves the likelihood of successful first-pass hardware bring-up.

---

# Related Documents

- 05_Power_Architecture.md
- 07_PCB_Design.md
- 08_Signal_Integrity.md

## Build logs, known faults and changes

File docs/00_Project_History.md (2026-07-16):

# Project History

## Introduction

This document records the engineering journey of the USB 3.1 Gen 1 to Gigabit Ethernet Adapter project.

Rather than serving as a development log or commit history, this document explains the reasoning behind major design decisions, architectural choices, and the evolution of the hardware throughout the project lifecycle.

Its purpose is to preserve engineering knowledge that would otherwise be lost after the project is completed.

---

# 1. Initial Objective

The objective of this project was to design a custom USB 3.1 Gen 1 to Gigabit Ethernet Adapter PCB capable of providing reliable Gigabit Ethernet connectivity over a USB interface.

The primary deliverable was a fabrication-ready hardware design rather than firmware or software.

From the beginning, emphasis was placed on understanding the complete hardware architecture instead of merely reproducing a reference design.

---

# 2. Design Philosophy

Several principles guided the development of this project.

- Every component should have a defined purpose.
- Every connection should be understood before implementation.
- Datasheets should be treated as the primary source of information.
- Reference designs should be studied, not blindly copied.
- PCB layout should be driven by signal integrity requirements rather than aesthetics.
- The design should remain maintainable and easy to review.

This philosophy significantly increased the design time but resulted in a much deeper understanding of the hardware.

---

# 3. Learning Before Designing

The project began with an extensive study phase.

Instead of immediately creating schematics, each major integrated circuit was studied individually.

Topics included:

- Device architecture
- Pin functions
- Power requirements
- Clock requirements
- Reset sequencing
- Configuration methods
- Interface standards
- Recommended layout practices

Only after understanding these topics was schematic capture started.

---

# 4. System Partitioning

Rather than viewing the adapter as a single PCB, it was divided into several independent functional blocks.

These blocks included:

- USB Interface
- Ethernet Controller
- Gigabit PHY
- Power Supply
- EEPROM
- Clock Generation
- Ethernet Magnetics
- Protection Circuits

Treating each subsystem independently simplified both design and verification.

---

# 5. Schematic Development

The schematic was developed incrementally.

Instead of completing one large schematic, each subsystem was reviewed multiple times before proceeding to the next.

Particular attention was given to:

- Power connections
- Decoupling capacitors
- Pull-up and pull-down resistors
- Strap pins
- Clock circuitry
- Reset circuitry
- Differential pair connectivity

Multiple iterations were performed before considering the schematic complete.

---

# 6. PCB Design

PCB development focused on achieving a layout suitable for high-speed digital communication.

Major considerations included:

- Four-layer stack-up
- Continuous reference planes
- Controlled impedance routing
- Return current paths
- Component placement
- Differential pair matching
- Power integrity
- Manufacturability

Placement was finalized before routing began.

Routing was performed subsystem by subsystem instead of net by net.

---

# 7. Verification

Before manufacturing, every stage of the design underwent verification.

Verification included:

- Electrical Rule Check (ERC)
- Design Rule Check (DRC)
- Net connectivity review
- Power rail verification
- Differential pair inspection
- Decoupling placement review
- Connector orientation verification

The objective was to eliminate preventable manufacturing issues before fabrication.

---

# 8. Current State

At the current stage, the hardware design has reached fabrication readiness.

The remaining work primarily consists of:

- Final manufacturing review
- PCB fabrication
- Assembly
- Hardware bring-up
- Functional validation
- Performance testing

---

# 9. Future Documentation

The remainder of the project documentation expands each subsystem individually.

Separate documents describe:

- System Architecture
- USB Subsystem
- Ethernet Subsystem
- Power Architecture
- PCB Design Methodology
- Signal Integrity Considerations
- Manufacturing Preparation
- Debugging History

Together these documents form the complete engineering record of the project.

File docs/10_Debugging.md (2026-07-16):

# Debugging

## 1. Introduction

This document provides a systematic debugging procedure for the USB 3.1 Gen 1 to Gigabit Ethernet Adapter after PCB assembly.

The objective is to isolate hardware faults in a logical order, beginning with the power subsystem and progressing through USB communication, Ethernet initialization, and network functionality.

The recommended approach is to verify one subsystem at a time rather than attempting full system validation immediately after power-up.

---

# 2. Required Equipment

The following equipment is recommended during hardware bring-up:

- Digital Multimeter (DMM)
- Oscilloscope
- USB Protocol Analyzer (optional)
- Ethernet Cable
- Gigabit Ethernet Switch or Router
- Computer with USB 3.x Port
- Bench Power Supply (if external power testing is required)

---

# 3. Debugging Sequence

Hardware should always be verified in the following order:

```
Visual Inspection
        │
        ▼
Continuity Check
        │
        ▼
Power Rails
        │
        ▼
Clock Verification
        │
        ▼
Reset Signals
        │
        ▼
EEPROM Detection
        │
        ▼
USB Enumeration
        │
        ▼
PHY Initialization
        │
        ▼
Ethernet Link
        │
        ▼
Network Communication
```

Skipping intermediate stages may make fault isolation significantly more difficult.

---

# 4. Visual Inspection

Before applying power, inspect the PCB for manufacturing defects.

Verify:

- Component orientation
- Missing components
- Solder bridges
- Lifted pins
- Poor solder joints
- Damaged traces
- Connector alignment

Correct any visible defects before continuing.

---

# 5. Continuity Checks

With the board unpowered:

- Verify there are no shorts between power and ground.
- Check continuity of all power rails.
- Confirm USB VBUS is not shorted.
- Verify Ethernet differential pairs are not shorted.
- Inspect regulator outputs for shorts.

These checks reduce the risk of damaging components during first power-up.

---

# 6. Power Verification

After connecting USB power:

Verify:

- VBUS present
- 3.3 V rail
- 1.2 V rail

Each regulator should reach its nominal output voltage and remain stable.

If any rail is missing or unstable:

- Disconnect power immediately.
- Inspect regulator circuitry.
- Verify component orientation.
- Check surrounding passive components.

Do not proceed until all power rails are operating correctly.

---

# 7. Clock Verification

Using an oscilloscope, verify the presence of the reference clock.

Check:

- Oscillation starts after power-up.
- Stable waveform.
- Expected frequency.
- Clean signal without excessive noise.

If no oscillation is observed:

- Inspect crystal connections.
- Verify load capacitors.
- Confirm regulator outputs.
- Inspect the surrounding layout.

---

# 8. EEPROM Verification

Confirm that the EEPROM is correctly powered and connected.

Verify:

- Supply voltage
- Communication lines
- Device orientation

If the controller cannot read configuration data, USB enumeration may fail or default configuration values may be used.

---

# 9. USB Enumeration

Connect the adapter to a host computer.

Verify:

- Device detection
- Correct Vendor ID
- Correct Product ID
- Successful enumeration
- Driver loading

If enumeration fails:

- Verify USB differential pairs.
- Inspect CC circuitry.
- Confirm EEPROM operation.
- Recheck power rails.
- Inspect the LAN7801 solder joints.

---

# 10. PHY Verification

After successful USB initialization, verify PHY operation.

Check:

- PHY power rails
- Reset signal
- Clock input
- MDIO communication
- Link status

If the PHY does not initialize correctly:

- Verify RGMII routing.
- Inspect strap pins.
- Confirm clock operation.
- Verify regulator outputs.

---

# 11. Ethernet Link Verification

Connect the adapter to a known-good Gigabit Ethernet switch.

Verify:

- Link LED
- Activity LED
- Auto-negotiation
- Link speed

Failure to establish link may indicate:

- PHY configuration issues
- Magnetics problems
- RJ45 soldering defects
- MDI routing faults

---

# 12. Functional Testing

Once a valid Ethernet link is established, perform functional testing.

Recommended tests include:

- IP address acquisition
- Ping test
- File transfer
- Sustained network traffic
- Throughput measurement

Observe the board for any instability during prolonged operation.

---

# 13. Common Symptoms

| Symptom | Possible Cause |
|---|---|
| No Power | USB connector, regulator, short circuit |
| Missing 3.3 V | LDO fault, shorted load |
| Missing 1.2 V | Core regulator fault |
| No Clock | Crystal or oscillator circuitry |
| USB Not Detected | USB routing, CC pins, LAN7801 |
| Enumeration Failure | EEPROM, controller configuration |
| No Ethernet Link | PHY, MagJack, MDI routing |
| Intermittent Link | Signal integrity or soldering issues |

---

# 14. Debugging Philosophy

Always isolate one subsystem before moving to the next.

Avoid making multiple hardware changes simultaneously, as this makes it difficult to identify the true source of a fault.

After every modification:

- Inspect the PCB.
- Repeat continuity checks if necessary.
- Re-verify the affected subsystem before proceeding.

A structured debugging process is significantly more effective than random trial-and-error.

---

# 15. Summary

Successful bring-up depends on verifying the hardware in a logical sequence.

Beginning with the power subsystem and progressing through clocks, configuration memory, USB communication, and Ethernet functionality minimizes debugging time and simplifies fault isolation.

This procedure should be followed whenever a new revision of the hardware is assembled.

---

# Related Documents

- 05_Power_Architecture.md
- 06_EEPROM.md
- 07_PCB_Design.md
- 08_Signal_Integrity.md
- 09_Manufacturing.md

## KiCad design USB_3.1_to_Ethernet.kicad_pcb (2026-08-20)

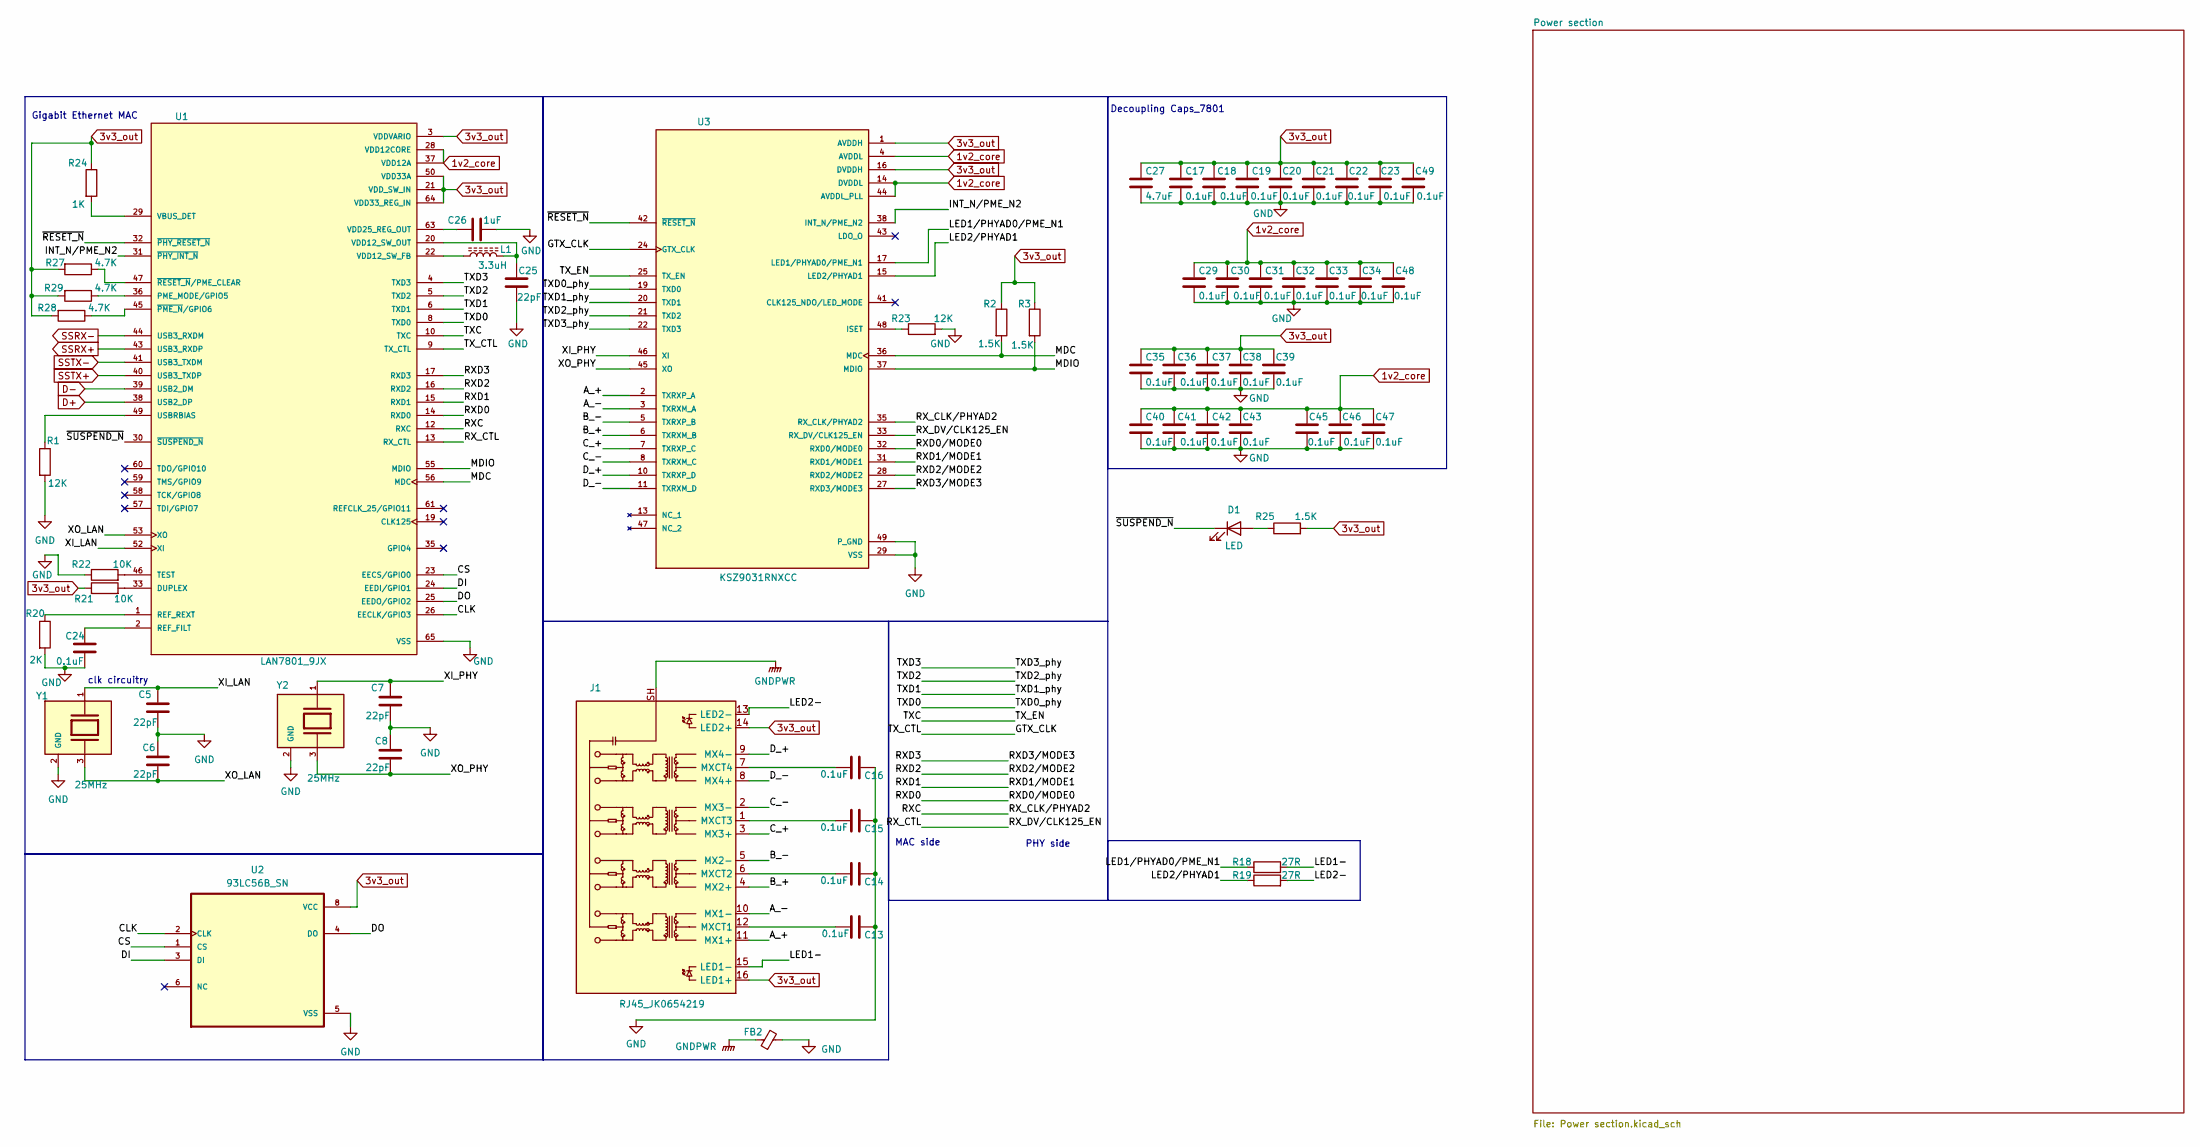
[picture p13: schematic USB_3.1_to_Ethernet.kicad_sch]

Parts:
C5, C6, C7, C8: 22pF; C_0402_1005Metric
C13, C14, C15, C16: 0.1uF; C_0402_1005Metric
C17, C18, C19, C20, C21, C22, C23, C24, C29, C30, C31, C32, C33, C34, C35, C36, C37, C38, C39, C40, C41, C42, C43, C45, C46, C47, C48, C49: 0.1uF; C_01005_0402Metric
C25: 22pF; C_01005_0402Metric
C26: 1uF; C_01005_0402Metric
C27: 4.7uF; C_01005_0402Metric
D1: LED; LED_01005_0402Metric
FB2: FerriteBead_Small; L_0402_1005Metric
J1: RJ45_JK0654219; RJ45_Pulse_JK0654219NL_Horizontal
L1: 3.3uH; L_0402_1005Metric
R1, R23: 12K; R_0402_1005Metric
R2, R3, R25: 1.5K; R_0402_1005Metric
R18, R19: 27R; R_0402_1005Metric
R20: 2K; R_0402_1005Metric
R21, R22: 10K; R_0402_1005Metric
R24: 1K; R_0402_1005Metric
R27, R28, R29: 4.7K; R_0402_1005Metric
U1: LAN7801_9JX; QFN50P900X900X100-65N_LAN7801_9JX; PARTREV DS00002123F
U2: 93LC56B_SN; 93LC56B_SOIC_8
U3: KSZ9031RNXCC; IC_KSZ9031RNXCC; PARTREV 07-09-24
Y1, Y2: 25MHz; Crystal_SMD_3225-4Pin_3.2x2.5mm; PARTREV August 01, 2022

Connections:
1v2_core: C29.1, C30.1, C31.1, C32.1, C33.1, C34.1, C40.1, C41.1, C42.1, C43.1, C45.1, C46.1, C47.1, C48.1, U1.28 (VDD12CORE), U1.37 (VDD12A), U1.42 (VDD12A), U1.54 (VDD12CORE), U1.62 (VDD12A), U3.4 (AVDDL), U3.9 (AVDDL), U3.14 (DVDDL), U3.18 (DVDDL), U3.23 (DVDDL), U3.26 (DVDDL), U3.30 (DVDDL), U3.39 (DVDDL), U3.44 (AVDDL_PLL); also elsewhere on the board
3v3_out: C17.1, C18.1, C19.1, C20.1, C21.1, C22.1, C23.1, C27.1, C35.1, C36.1, C37.1, C38.1, C39.1, C49.1, J1.14 (LED2+), J1.16 (LED1+), R2.1, R3.1, R21.1, R24.1, R25.2, R27.2, R28.2, R29.2, U1.3 (VDDVARIO), U1.7 (VDDVARIO), U1.11 (VDDVARIO), U1.18 (VDDVARIO), U1.21 (VDD_SW_IN), U1.27 (VDDVARIO), U1.48 (VDDVARIO), U1.50 (VDD33A), U1.51 (VDDVARIO), U1.64 (VDD33_REG_IN), U2.8 (VCC), U3.1 (AVDDH), U3.12 (AVDDH), U3.16 (DVDDH), U3.34 (DVDDH), U3.40 (DVDDH); also elsewhere on the board
/A_+: J1.11 (MX1+), U3.2 (TXRXP_A)
/A_-: J1.10 (MX1-), U3.3 (TXRXM_A)
/B_+: J1.4 (MX2+), U3.6 (TXRXM_B)
/B_-: J1.5 (MX2-), U3.5 (TXRXP_B)
/CLK: U1.26 (EECLK/GPIO3), U2.2 (CLK)
/CS: U1.23 (EECS/GPIO0), U2.1 (CS)
/C_+: J1.3 (MX3+), U3.7 (TXRXP_C)
/C_-: J1.2 (MX3-), U3.8 (TXRXM_C)
/DI: U1.24 (EEDI/GPIO1), U2.3 (DI)
/DO: U1.25 (EEDO/GPIO2), U2.4 (DO)
/D_+: J1.9 (MX4-), U3.10 (TXRXP_D)
/D_-: J1.8 (MX4+), U3.11 (TXRXM_D)
/GTX_CLK: U1.9 (TX_CTL), U3.24 (GTX_CLK)
/INT_N/PME_N2: U1.31 (~PHY_INT_N), U3.38 (INT_N/PME_N2)
/LED1-: J1.15 (LED1-), R18.2
/LED1/PHYAD0/PME_N1: R18.1, U3.17 (LED1/PHYAD0/PME_N1)
/LED2-: J1.13 (LED2-), R19.2
/LED2/PHYAD1: R19.1, U3.15 (LED2/PHYAD1)
/MDC: R2.2, U1.56 (MDC), U3.36 (MDC)
/MDIO: R3.2, U1.55 (MDIO), U3.37 (MDIO)
/RXD0: U1.14 (RXD0), U3.32 (RXD0/MODE0)
/RXD1: U1.15 (RXD1), U3.31 (RXD1/MODE1)
/RXD2: U1.16 (RXD2), U3.28 (RXD2/MODE2)
/RXD3: U1.17 (RXD3), U3.27 (RXD3/MODE3)
/RX_CTL: U1.13 (RX_CTL), U3.33 (RX_DV/CLK125_EN)
/TXC: U1.10 (TXC), U3.25 (TX_EN)
/TXD0: U1.8 (TXD0), U3.19 (TXD0)
/TXD1: U1.6 (TXD1), U3.20 (TXD1)
/TXD2: U1.5 (TXD2), U3.21 (TXD2)
/TXD3: U1.4 (TXD3), U3.22 (TXD3)
/XI_LAN: C5.1, U1.52 (XI), Y1.1
/XI_PHY: C7.1, U3.46 (XI), Y2.1
/XO_LAN: C6.2, U1.53 (XO), Y1.3
/XO_PHY: C8.2, U3.45 (XO), Y2.3
/~RESET_N: U1.32 (~PHY_RESET_N), U3.42 (~RESET_N)
/~SUSPEND_N: D1.1 (K), U1.30 (~SUSPEND_N)
D+: U1.38 (USB2_DP); also elsewhere on the board
D-: U1.39 (USB2_DM); also elsewhere on the board
GND: C5.2, C6.1, C7.2, C8.1, C13.1, C14.1, C15.1, C16.1, C17.2, C18.2, C19.2, C20.2, C21.2, C22.2, C23.2, C24.2, C25.2, C26.2, C27.2, C29.2, C30.2, C31.2, C32.2, C33.2, C34.2, C35.2, C36.2, C37.2, C38.2, C39.2, C40.2, C41.2, C42.2, C43.2, C45.2, C46.2, C47.2, C48.2, C49.2, FB2.2, R1.2, R20.2, R22.1, R23.2, U1.65 (VSS), U2.5 (VSS), U3.29 (VSS), U3.49 (P_GND), U3.49_1 (P_GND), U3.49_2 (P_GND), U3.49_3 (P_GND), U3.49_4 (P_GND), U3.49_5 (P_GND), U3.49_6 (P_GND), U3.49_7 (P_GND), U3.49_8 (P_GND), U3.49_9 (P_GND), U3.49_10 (P_GND), U3.49_11 (P_GND), U3.49_12 (P_GND), U3.49_13 (P_GND), U3.49_14 (P_GND), U3.49_15 (P_GND), U3.49_16 (P_GND), U3.49_17 (P_GND), U3.49_18 (P_GND), U3.49_19 (P_GND), U3.49_20 (P_GND), U3.49_21 (P_GND), U3.49_22 (P_GND), U3.49_23 (P_GND), U3.49_24 (P_GND), U3.49_25 (P_GND), Y1.2 (GND), Y1.4 (GND), Y2.2 (GND), Y2.4 (GND); also elsewhere on the board
GNDPWR: FB2.1, J1.SH
unnamed: D1.2 (A), R25.1
unnamed: C13.2, J1.12 (MXCT1)
unnamed: C14.2, J1.6 (MXCT2)
unnamed: C15.2, J1.1 (MXCT3)
unnamed: C16.2, J1.7 (MXCT4)
unnamed: R21.2, U1.33 (DUPLEX)
unnamed: R29.1, U1.36 (PME_MODE/GPIO5)
unnamed: C24.1, U1.2 (REF_FILT)
unnamed: R20.1, U1.1 (REF_REXT)
unnamed: R22.2, U1.46 (TEST)
unnamed: R1.1, U1.49 (USBRBIAS)
unnamed: R24.2, U1.29 (VBUS_DET)
unnamed: L1.1, U1.22 (VDD12_SW_FB)
unnamed: C25.1, L1.2, U1.20 (VDD12_SW_OUT)
unnamed: C26.1, U1.63 (VDD25_REG_OUT)
unnamed: R28.1, U1.45 (~PME_N/GPIO6)
unnamed: R27.1, U1.47 (~RESET_N/PME_CLEAR)
unnamed: R23.1, U3.48 (ISET)
SSRX+: U1.43 (USB3_RXDP); also elsewhere on the board
SSRX-: U1.44 (USB3_RXDM); also elsewhere on the board
SSTX+: U1.40 (USB3_TXDP); also elsewhere on the board
SSTX-: U1.41 (USB3_TXDM); also elsewhere on the board

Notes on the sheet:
Decoupling Caps_7801
clk circuitry
Gigabit Ethernet MAC
PHY side
MAC side

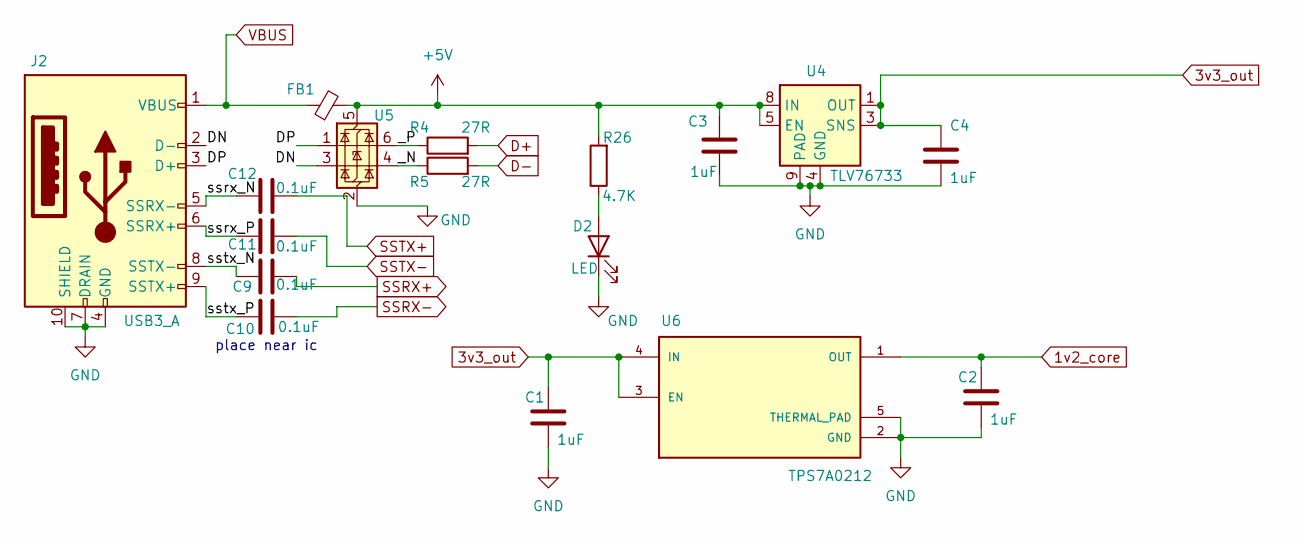
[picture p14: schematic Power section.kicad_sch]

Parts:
C1, C2, C3, C4: 1uF; C_0402_1005Metric
C9, C10, C11, C12: 0.1uF; C_0402_1005Metric
D2: LED; LED_01005_0402Metric
FB1: FerriteBead_Small; L_0402_1005Metric
J2: USB3_A; USB3_A_Plug_Wuerth_692112030100_Horizontal
R4, R5: 27R; R_0402_1005Metric
R26: 4.7K; R_0402_1005Metric
U4: TLV76733; VSON-8-1EP_3x3mm_P0.65mm_EP1.65x2.4mm_ThermalVias
U5: USBLC6-2P6; SOT-666
U6: TPS7A0212; Tps_7a0212; PARTREV C

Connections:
1v2_core: C2.1, U6.1 (OUT); also elsewhere on the board
3v3_out: C1.1, C4.1, U4.1 (OUT), U4.3 (SNS), U6.3 (EN), U6.4 (IN); also elsewhere on the board
+5V: C3.1, FB1.2, R26.2, U4.5 (EN), U4.8 (IN), U5.5 (VBUS)
/Power section/DN: J2.2 (D-), U5.3 (I/O2)
/Power section/DP: J2.3 (D+), U5.1 (I/O1)
/Power section/_N: R5.1, U5.4 (I/O2)
/Power section/_P: R4.1, U5.6 (I/O1)
/Power section/ssrx_N: C12.1, J2.5 (SSRX-)
/Power section/ssrx_P: C11.1, J2.6 (SSRX+)
/Power section/sstx_N: C9.1, J2.8 (SSTX-)
/Power section/sstx_P: C10.1, J2.9 (SSTX+)
D+: R4.2; also elsewhere on the board
D-: R5.2; also elsewhere on the board
GND: C1.2, C2.2, C3.2, C4.2, D2.1 (K), J2.4 (GND), J2.7 (DRAIN), J2.10 (SHIELD), U4.4 (GND), U4.6 (GND), U4.9 (PAD), U5.2 (GND), U6.2 (GND), U6.5 (THERMAL_PAD); also elsewhere on the board
unnamed: D2.2 (A), R26.1
SSRX+: C9.2; also elsewhere on the board
SSRX-: C10.2; also elsewhere on the board
SSTX+: C12.2; also elsewhere on the board
SSTX-: C11.2; also elsewhere on the board
VBUS: FB1.1, J2.1 (VBUS)

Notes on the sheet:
place near ic

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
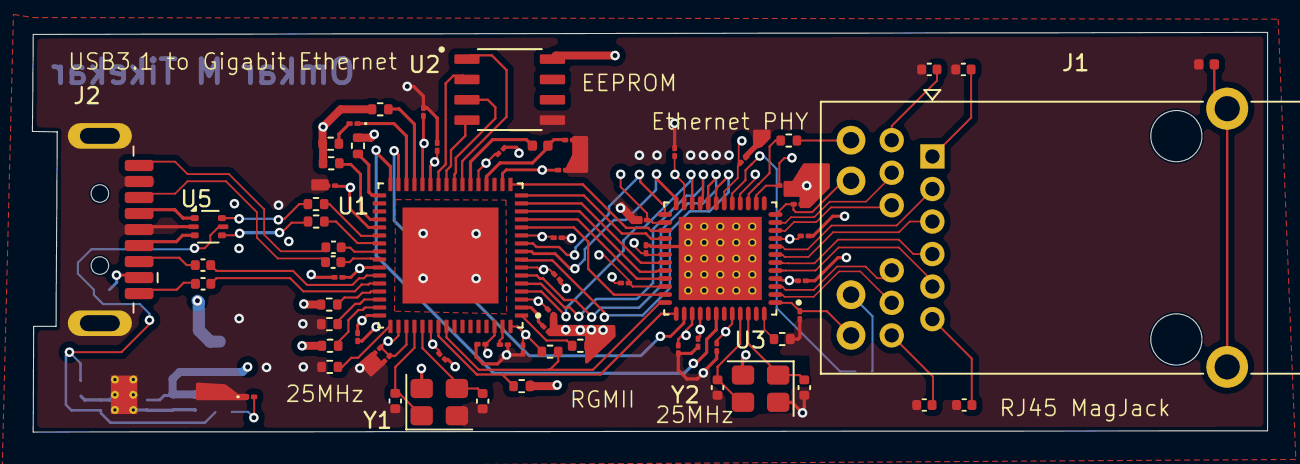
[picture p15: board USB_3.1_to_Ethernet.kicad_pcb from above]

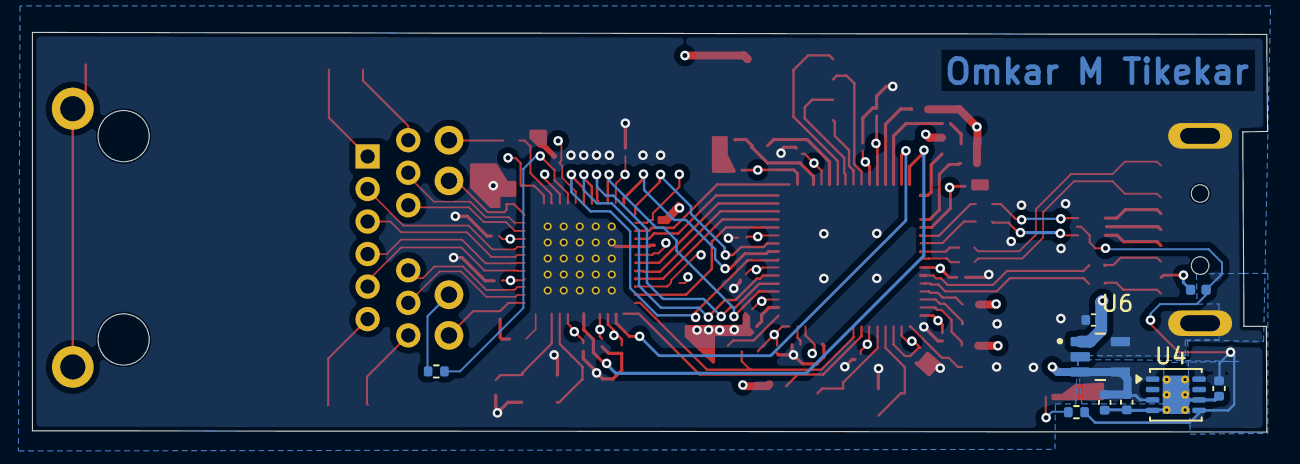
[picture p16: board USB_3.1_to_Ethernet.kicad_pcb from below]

Board: 4 copper layers, 77.2 x 25.0 mm, 79 parts (9 on the bottom side), 76 nets.

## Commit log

2026-04-10 usb connector added
    [USB_3.1_to_Ethernet.kicad_sch]
2026-04-10 power section added and power connections done
    [USB_3.1_to_Ethernet.kicad_sch, untitled.kicad_sch]
2026-04-10 power section added and power connections made
    [Power section.kicad_sch, USB_3.1_to_Ethernet.kicad_pcb]
2026-04-10 power section added and power conections made
    [USB_3.1_to_Ethernet.kicad_sch]
2026-04-10 usb connections done without 27 ohm, SMI connections done, EEPROM connections done.
    [Power section.kicad_sch, USB_3.1_to_Ethernet.kicad_pcb, USB_3.1_to_Ethernet.kicad_sch]
2026-04-10 RGMII connections made, Clk circuitry made, 27 ohm resistors added
    [Power section.kicad_sch, USB_3.1_to_Ethernet.kicad_pcb, USB_3.1_to_Ethernet.kicad_sch]
2026-04-13 Added 27R resistors to RGMII interface, added 0.1uF AC coupling caps on sstx/rx, Magjack connections done
    [Power section.kicad_sch, USB_3.1_to_Ethernet.kicad_pcb, USB_3.1_to_Ethernet.kicad_sch]
2026-05-09 no major changes, APll tied to 3v3
    [Power section.kicad_sch, USB_3.1_to_Ethernet.kicad_sch]
2026-05-09 1. Decoupling capacitors for Lan7801 ic added 2. 3.3v Input given to TPS7A0212 instead of 5v 3. Ref+Rfilt resistor capacitor added 4. Iset resistor 12K added 5. Test Pull-down and Duplex Pull-up 10K 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
    [Power section.kicad_sch, USB_3.1_to_Ethernet.kicad_sch]
2026-05-23 1. Layout placement started. placed Lan7801, PHY, EEPROM and regulators 2.changed D+ D- lines of USB-TVS diode reveresed for clean routing
    [Power section.kicad_sch, USB_3.1_to_Ethernet.kicad_pcb, USB_3.1_to_Ethernet.kicad_sch]
2026-05-24 merged with main branch, no major change in pcb or schematics
    [Power section.kicad_sch, USB_3.1_to_Ethernet.kicad_pcb]
2026-05-26 1. net class assigned to all the nets 2.Slight placement changes
    [Power section.kicad_sch, USB_3.1_to_Ethernet.kicad_pcb]
2026-05-27 1. Major routing done- usb3.1,usb2, >> 2. buck converter and voltage regulators placement and routing done >> 3. Decoupling caps added
    [Power section.kicad_sch, USB_3.1_to_Ethernet.kicad_pcb, USB_3.1_to_Ethernet.kicad_sch]
2026-05-27 1. usb routing done 2.clock routing done 3. decoupling capacitors(3.3v) routing for lan7801 ic done
    [Power section.kicad_sch, USB_3.1_to_Ethernet.kicad_pcb]
2026-05-29 1. RGMII routing done - LAN7801 RXD 2.Routing for RGMII - TXD on top layer done, bottom layer remaining 3. source termination resistors 27 ohm removed for RGMII
    [USB_3.1_to_Ethernet.kicad_pcb, USB_3.1_to_Ethernet.kicad_sch]
2026-05-30 rgmii routing completed
    [USB_3.1_to_Ethernet.kicad_pcb]
2026-05-30 1.complete routing done 2.Ethernet MDI differential routing done 3.power and gnd plane on L2 and L3 completed 4.
    [USB_3.1_to_Ethernet.kicad_pcb, USB_3.1_to_Ethernet.kicad_sch]
2026-05-30 microadjustments in via connections of gnd
    [USB_3.1_to_Ethernet.kicad_pcb, USB_3.1_to_Ethernet.kicad_sch]
2026-05-30 cleaned the DRC errors and step files of ICs included
    [USB_3.1_to_Ethernet.kicad_pcb]
2026-06-07 step file for usb A plug added. Modified edge cuts layer by adding a slot for usb connector'
    [A-USB3_A-LP-SMT1.step, USB_3.1_to_Ethernet.kicad_pcb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]
2026-06-07 adjusted via positions near the PHY ic
    [USB_3.1_to_Ethernet.kicad_pcb]
2026-06-07 tvs diode routing complete and improved usb2 routing
    [USB_3.1_to_Ethernet.kicad_pcb]
2026-06-12 step files for all the component added
    [USB_3.1_to_Ethernet.kicad_pcb]
2026-07-09 improved RGMII routing on bottom layer
    [USB_3.1_to_Ethernet.kicad_pcb]
2026-07-16 some minor changes in the routing
    [USB_3.1_to_Ethernet.kicad_pcb, USB_3.1_to_Ethernet.kicad_sch]
2026-07-16 DRC cleared to 0 errors
    [USB_3.1_to_Ethernet.kicad_pcb]
2026-07-18 Step files added for ics
    [93LC56-I_SN.STEP, KSZ9031RNXIC.STEP, LAN7801_9JX.STEP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]
2026-07-18 Datasheets for all the ICs added iin the Docs folder
    [Power section.kicad_sch, USB_3.1_to_Ethernet.kicad_pcb]
2026-07-18 Change USB Type-C references to USB Type-A
    Updated references from USB Type-C to USB Type-A connector throughout the document. Adjusted section headings and descriptions accordingly.
2026-07-18 Correct USB connector reference in PCB design
2026-07-19 images for the pcb and schematics added
2026-07-21 resolved drc errors of shorting nets
    [USB_3.1_to_Ethernet.kicad_pcb, USB_3.1_to_Ethernet.kicad_sch]
2026-08-14 open gnd vias controlled pour spillage and improved clck circuitry
    [USB_3.1_to_Ethernet.kicad_pcb]
2026-08-20 added gnd stitching vias near rgmii interface for short return current loop
    [USB_3.1_to_Ethernet.kicad_pcb]
